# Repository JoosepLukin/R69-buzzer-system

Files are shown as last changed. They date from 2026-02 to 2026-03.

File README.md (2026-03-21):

# R69 Buzzer System

A wireless buzzer/alert system built on three custom PCBs communicating via ESP-NOW, RS-485, and 433 MHz RF. The system is designed for event/competition use where remote flash+buzzer units (Vilkur) are triggered from a central control panel (KontrollKast) with an RF-bridge board in between.

---

## System Architecture

```
                        ┌──────────────┐
  [433 MHz Remote] ────►│   Vilkur     │──── LEDs + Buzzer
                   ──┐  │  (ESP32-C3)  │
                     │  └──────────────┘
                     │         ▲▼ ESP-NOW
                     │  ┌──────────────────────┐
                     └─►│  SaatjaVastuvõtja    │
                        │     (ESP32-C3)        │
                        │  433 MHz RX + ESP-NOW │
                        └──────────┬───────────┘
                                   │ RS-485 (Cat5 cable, 12 V + GND)
                        ┌──────────▼───────────┐
                        │    KontrollKast       │
                        │      (ESP32-S3)       │
                        │  Touchscreen + Buttons│
                        │  RS-485 + 433 MHz RX  │
                        └──────────────────────┘
```

### Communication flows

| Path | Protocol | Purpose |
|---|---|---|
| KontrollKast ↔ SaatjaVastuvõtja | RS-485 JSON (115200 baud) | Commands, status, sensor data |
| SaatjaVastuvõtja ↔ Vilkur | ESP-NOW (2.4 GHz) | Blink commands, pings, status |
| 433 MHz Remote → Vilkur | ASK/OOK PT2262/EV1527 | Direct trigger (fallback) |
| 433 MHz Remote → SaatjaVastuvõtja | ASK/OOK PT2262/EV1527 | Relay to KontrollKast |
| 433 MHz Remote → KontrollKast | ASK/OOK PT2262/EV1527 | Pairing only |

---

## PCB Overview

### PCB 1 — Vilkur (`Vilkur/`)
The flash/buzzer unit. Runs on a 3S Li-ion battery pack with BMS and USB-C charging. Drives two LED groups and a piezo buzzer via N-channel MOSFETs. Listens for both ESP-NOW commands and 433 MHz RF signals (433 MHz acts as a fallback: it is automatically disabled when ESP-NOW messages are active and re-enabled after 1 minute of silence).

- **MCU**: ESP32-C3 Supermini
- **Power**: 3S 18650 Li-ion → BMS → 12 V boost → 3.3 V buck
- **Outputs**: LED group 1, LED group 2, piezo buzzer (all MOSFET low-side)
- **Inputs**: 433 MHz RXB6, rotary channel switch, pairing button, external trigger, battery ADC

### PCB 2 — KontrollKast (`KontrollKast/`)
The control centre. Powered from 12 V mains/PSU. Features a 320×480 touchscreen for configuration and status, three illuminated push-buttons for manual triggering, a 433 MHz receiver for pairing remotes, and an RS-485 link to SaatjaVastuvõtja.

- **MCU**: ESP32-S3
- **Display**: ST7796 320×480 SPI + FT6336U capacitive touch
- **Outputs**: 3× button backlight LEDs (MOSFET low-side, 12 V)
- **Inputs**: 3× push-buttons, 433 MHz RXB6 (pairing only)
- **Comms**: RS-485 (SN65HVD72) to SaatjaVastuvõtja

### PCB 3 — SaatjaVastuvõtja (`SaatjaVastuvõtja/`)
The RF bridge. Powered over Cat5 from KontrollKast (12 V). Receives 433 MHz signals and ESP-NOW messages, relaying everything to KontrollKast over RS-485. Sends ESP-NOW commands to Vilkur units based on instructions from KontrollKast.

- **MCU**: ESP32-C3 Supermini
- **Inputs**: 433 MHz RXB6, ESP-NOW from Vilkur
- **Comms**: RS-485 (SN65HVD72) to KontrollKast, ESP-NOW to Vilkur

---

## RS-485 JSON Protocol

All frames are UTF-8 text terminated with `\n`. Baud rate: **115200, 8N1**.

### SaatjaVastuvõtja → KontrollKast

```json
{"type":"433rx","code":12345678,"bits":24}
{"type":"espnow_rx","mac":"AA:BB:CC:DD:EE:FF","cmd":"blink","battery":3.72}
{"type":"ping_reply","mac":"AA:BB:CC:DD:EE:FF","battery":3.72}
{"type":"espnow_ack","mac":"AA:BB:CC:DD:EE:FF","success":true}
```

### KontrollKast → SaatjaVastuvõtja

```json
{"type":"cmd","mac":"AA:BB:CC:DD:EE:FF","action":"blink","duration":5000,"buzzer":true}
{"type":"cmd","mac":"broadcast","action":"stop"}
{"type":"cmd","mac":"AA:BB:CC:DD:EE:FF","action":"disable_433"}
{"type":"ping","mac":"AA:BB:CC:DD:EE:FF"}
{"type":"ping","mac":"broadcast"}
{"type":"pair_enable"}
```

---

## ESP-NOW Message Structure

```cpp
// Shared between Vilkur and SaatjaVastuvõtja
struct EspNowMsg {
    uint8_t  cmd;       // see CMD_* constants below
    uint16_t duration;  // blink duration ms
    bool     buzzer;    // enable buzzer during blink
    float    battery;   // Vilkur battery voltage (V), sent in pong
};

// cmd values
#define CMD_BLINK       0x01
#define CMD_STOP        0x02
#define CMD_DISABLE_433 0x03
#define CMD_PING        0x04
#define CMD_PONG        0x05
```

---

## Directory Structure

```
R69-buzzer-system/
├── README.md                        ← this file
├── Vilkur/
│   ├── README.md                    ← Vilkur detailed docs
│   └── Vilkur_Test/
│       └── Vilkur_Test.ino          ← Arduino test sketch (ESP32-C3)
├── KontrollKast/
│   ├── README.md                    ← KontrollKast detailed docs
│   └── KontrollKast_Test/
│       └── KontrollKast_Test.ino    ← Arduino test sketch (ESP32-S3)
├── SaatjaVastuvõtja/
│   ├── README.md                    ← SaatjaVastuvõtja detailed docs
│   └── SaatjaVastuvõtja_Test/
│       └── SaatjaVastuvõtja_Test.ino ← Arduino test sketch (ESP32-C3)
├── Altium/                          ← PCB design files (Altium Designer)
│   ├── Buzzer/                      ← Vilkur PCB
│   ├── KontrollKast/                ← KontrollKast PCB
│   └── VastuvotjaMoodul/            ← SaatjaVastuvõtja PCB
└── ESP-NOW Mõõtmised/               ← Range/latency measurement data & visualiser
```

---

## Required Arduino Libraries

| Library | Board | Install via |
|---|---|---|
| `esp_now.h` + `WiFi.h` | All | Built-in (ESP32 Arduino core) |
| RCSwitch | Vilkur, KontrollKast, SaatjaVastuvõtja | Arduino Library Manager |
| TFT_eSPI | KontrollKast | Arduino Library Manager |
| ArduinoJson (v6) | KontrollKast, SaatjaVastuvõtja | Arduino Library Manager |

### Arduino Board Packages
- **ESP32-C3 Supermini**: `esp32` by Espressif, board `ESP32C3 Dev Module`
- **ESP32-S3**: `esp32` by Espressif, board `ESP32S3 Dev Module`

### TFT_eSPI Configuration (KontrollKast)
Edit `libraries/TFT_eSPI/User_Setup.h`:
```cpp
#define ST7796_DRIVER
#define TFT_WIDTH  320
#define TFT_HEIGHT 480
#define TFT_CS    15
#define TFT_DC    17
#define TFT_RST   16
#define TFT_MOSI  18
#define TFT_SCLK   8
#define TFT_MISO   9
#define TFT_BL     3
#define SPI_FREQUENCY  27000000
```

---

## License

Apache License 2.0 — see [LICENSE](LICENSE).

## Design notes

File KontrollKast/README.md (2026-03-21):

# KontrollKast — Control Centre

PCB 2 of the R69 Buzzer System. The central control unit. Powered from a 12 V supply, it provides a touchscreen UI for configuration and status, three illuminated push-buttons for direct triggering, and communicates with Vilkur units indirectly through SaatjaVastuvõtja over RS-485. All ESP-NOW traffic passes through SaatjaVastuvõtja — KontrollKast itself has no wireless radio beyond the local 433 MHz receiver used only for pairing.

---

## Hardware Summary

| Component | Details |
|---|---|
| MCU | ESP32-S3 |
| Power input | Barrel jack 12 V |
| Buck converter | 12 V → 3.3 V (ESP32 + logic) |
| Display | ST7796 320×480 SPI LCD |
| Touch | FT6336U capacitive touch (I2C, addr 0x38) |
| 433 MHz RX | RXB6 module (pairing only) |
| RS-485 transceiver | SN65HVD72DGKR (half-duplex) |
| RS-485 connector | Cat5 (also carries 12 V + GND to SaatjaVastuvõtja) |
| Buttons | 3× illuminated 12 V push-buttons |
| Button connectors | NS25 W4P: 12 V, GND, backlight MOSFET, button input GPIO |

---

## GPIO Pinout (ESP32-S3)

| GPIO | Direction | Function | Notes |
|---|---|---|---|
| 1 | Input | RXB6 433 MHz data | Pairing use only |
| 3 | Output | LCD backlight PWM | `ledcWrite` for brightness control |
| 4 | Output | RS-485 DE/RE (mode) | HIGH = transmit, LOW = receive |
| 5 | Output | RS-485 TX | Serial1 TX |
| 6 | Input | RS-485 RX | Serial1 RX |
| 8 | Output | LCD SCK (SPI) | Shared SPI bus |
| 9 | Input | LCD MISO (SPI) | Shared SPI bus |
| 10 | I/O | Touch CTP_SCL (I2C) | Wire SCL |
| 11 | Output | Touch CTP_RST | Active LOW reset |
| 12 | I/O | Touch CTP_SDA (I2C) | Wire SDA |
| 13 | Input | Touch CTP_INT | LOW when touch event pending |
| 14 | Output | SD card CS | SPI chip select |
| 15 | Output | LCD CS | SPI chip select |
| 16 | Output | LCD RST | Active LOW reset |
| 17 | Output | LCD DC (RS) | HIGH = data, LOW = command |
| 18 | Output | LCD MOSI (SPI) | Shared SPI bus |
| 21 | Output | Button 1 backlight MOSFET | Active HIGH |
| 35 | Output | Button 2 backlight MOSFET | Active HIGH |
| 36 | Input | Button 2 input | Active LOW (see W4P connector) |
| 39 | Output | Button 3 backlight MOSFET | Active HIGH |
| 40 | Input | Button 3 input | Active LOW |
| 48 | Input | Button 1 input | Active LOW |

---

## Button Connector (NS25 W4P)

Each button connector carries four signals:

| Pin | Signal |
|-----|---|
| 1 | 12 V (backlight LED +) |
| 2 | GND (switch common) |
| 3 | Backlight MOSFET drain → LED – |
| 4 | Button switch output → GPIO input |

The button switch is wired between pin 4 and GND (pin 2). The GPIO uses `INPUT_PULLUP`; pressing the button pulls it LOW.

---

## Display — ST7796 + FT6336U

### SPI LCD (ST7796, 320×480)
```
ESP32-S3 GPIO  │ Ribbon pin │ Function
───────────────┼────────────┼──────────────────
GPIO 15        │ LCD_CS     │ Chip select (active LOW)
GPIO 16        │ LCD_RST    │ Reset (active LOW)
GPIO 17        │ LCD_RS/DC  │ Command=LOW / Data=HIGH
GPIO 18        │ SDI/MOSI   │ SPI data in
GPIO  8        │ SCK        │ SPI clock
GPIO  9        │ SDO/MISO   │ SPI data out
GPIO  3        │ LED        │ Backlight (PWM)
3.3 V          │ VCC        │ Logic power (backlight dim at 3.3 V)
```

> **Note**: The module datasheet recommends 5 V for full backlight brightness. At 3.3 V the backlight will be slightly dimmer but fully functional.

### Capacitive Touch (FT6336U, I2C address 0x38)
```
ESP32-S3 GPIO  │ Ribbon pin │ Function
───────────────┼────────────┼──────────────────
GPIO 10        │ CTP_SCL    │ I2C clock
GPIO 12        │ CTP_SDA    │ I2C data
GPIO 11        │ CTP_RST    │ Controller reset (active LOW)
GPIO 13        │ CTP_INT    │ Touch interrupt (active LOW)
```

Key FT6336U registers (read via Wire at address 0x38):

| Register | Name | Description |
|---|---|---|
| 0x02 | TD_STATUS | Number of touch points (0 or 1) |
| 0x03 | P1_XH | Touch 1 X high byte (bits [3:0]) + event flag |
| 0x04 | P1_XL | Touch 1 X low byte |
| 0x05 | P1_YH | Touch 1 Y high byte (bits [3:0]) |
| 0x06 | P1_YL | Touch 1 Y low byte |

### TFT_eSPI Configuration

Add to `libraries/TFT_eSPI/User_Setup.h`:
```cpp
#define ST7796_DRIVER
#define TFT_WIDTH  320
#define TFT_HEIGHT 480
#define TFT_CS    15
#define TFT_DC    17
#define TFT_RST   16
#define TFT_MOSI  18
#define TFT_SCLK   8
#define TFT_MISO   9
#define TFT_BL     3
#define SPI_FREQUENCY     27000000
#define SPI_READ_FREQUENCY 20000000
```

---

## RS-485 Interface

- **Transceiver**: SN65HVD72DGKR (3.3 V, half-duplex)
- **Mode pin** (GPIO 4): HIGH = transmit (DE+RE asserted), LOW = receive
- **Baud rate**: 115200, 8N1
- **Physical**: Differential pair over Cat5 cable; same cable carries 12 V and GND to power SaatjaVastuvõtja

```cpp
Serial1.begin(115200, SERIAL_8N1, /*RX=*/6, /*TX=*/5);
```

Transmit procedure:
1. `digitalWrite(RS485_MODE, HIGH);`
2. `Serial1.println(jsonString);`
3. `Serial1.flush();`
4. `digitalWrite(RS485_MODE, LOW);`

---

## Behaviour Logic

### Startup
1. Initialize display → splash screen.
2. Initialize touch controller.
3. Initialize RS-485 and send a broadcast ping to discover connected Vilkur units.
4. Show main UI.

### Main UI (touchscreen)
- **Status panel**: Connected Vilkur list (MAC, battery voltage, last-seen).
- **Manual trigger buttons** (on screen and physical buttons):
  - Blink All — broadcast `CMD_BLINK` to all Vilkurs via RS-485 → SaatjaVastuvõtja
  - Stop All — broadcast `CMD_STOP`
  - Ping All — send ping broadcast; update status panel on reply
- **Settings page** (touch navigation):
  - Blink duration (ms)
  - Buzzer on/off during blink
  - ESP-NOW channel selection (must match rotary switch on Vilkur)
  - 433 MHz pairing mode

### Physical buttons
Each physical button (1, 2, 3) can be assigned to a specific Vilkur or broadcast group. Pressing a button sends `CMD_BLINK` to its assigned target. The corresponding backlight LED lights up while the Vilkur is blinking.

### 433 MHz pairing mode
Activated from the settings page or by a long-press on button 1. The on-board RXB6 receiver listens for the next PT2262/EV1527 code and stores it as an authorised trigger code. This code is then relayed to SaatjaVastuvõtja (and onward to Vilkurs) so that the remote directly triggers blinking.

### Vilkur monitoring (ping)
Every 5 seconds KontrollKast sends `{"type":"ping","mac":"broadcast"}` over RS-485. SaatjaVastuvõtja forwards this as ESP-NOW `CMD_PING`. Vilkur replies with `CMD_PONG` (including battery voltage). SaatjaVastuvõtja relays the reply back over RS-485 as `{"type":"ping_reply",...}`. KontrollKast marks the Vilkur as connected and updates its voltage on screen.

---

## Required Libraries

| Library | Source |
|---|---|
| TFT_eSPI | Arduino Library Manager |
| ArduinoJson (v6) | Arduino Library Manager |
| RCSwitch (by sui77) | Arduino Library Manager |
| `Wire.h` | Built-in (ESP32 Arduino core) |
| `HardwareSerial` | Built-in (ESP32 Arduino core) |

---

## Test Sketch

See [`KontrollKast_Test/KontrollKast_Test.ino`](KontrollKast_Test/KontrollKast_Test.ino).

The test sketch exercises:
- ST7796 display (colour fill, text rendering)
- FT6336U touch (live X/Y display)
- Three physical buttons + backlight LEDs
- 433 MHz reception (code displayed on screen + Serial)
- RS-485 TX/RX (periodic ping to SaatjaVastuvõtja, display replies)
- On-screen touch buttons: Blink All, Stop All, Ping All, 433 Pair

Open Serial monitor at **115200 baud** for debug output.

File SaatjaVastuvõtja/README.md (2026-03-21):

# SaatjaVastuvõtja — RF Bridge

PCB 3 of the R69 Buzzer System. A small bridge board that sits physically close to the event area and connects KontrollKast (wired, over Cat5 RS-485) to Vilkur units (wireless, ESP-NOW). It also forwards 433 MHz RF signals received from remotes to KontrollKast over RS-485.

The name combines the Estonian words *saatja* (sender) and *vastuvõtja* (receiver), reflecting its dual transmit/receive role.

---

## Hardware Summary

| Component | Details |
|---|---|
| MCU | ESP32-C3 Supermini |
| Power input | Cat5 connector — 12 V from KontrollKast |
| Buck converter | 12 V → 3.3 V (ESP32 + logic) |
| 433 MHz RX | RXB6 module |
| RS-485 transceiver | SN65HVD72DGKR (half-duplex, same chip as KontrollKast) |
| RS-485 connector | Cat5 (12 V, GND, RS-485 A/B from KontrollKast) |

---

## GPIO Pinout (ESP32-C3 Supermini)

| GPIO | Direction | Function | Notes |
|---|---|---|---|
| 1 | Output | RS-485 DE/RE (mode) | HIGH = transmit, LOW = receive |
| 2 | Output | RS-485 TX | Serial1 TX |
| 3 | Input | RS-485 RX | Serial1 RX |
| 4 | Input | RXB6 433 MHz data | Interrupt-driven |

---

## RS-485 Interface

- **Transceiver**: SN65HVD72DGKR, same as KontrollKast
- **Mode pin** (GPIO 1): HIGH = transmit, LOW = receive
- **Baud rate**: 115200, 8N1
- **Physical**: Differential pair over Cat5 cable to KontrollKast

```cpp
Serial1.begin(115200, SERIAL_8N1, /*RX=*/3, /*TX=*/2);
```

Transmit procedure:
1. `digitalWrite(RS485_MODE, HIGH);`
2. `Serial1.println(jsonString);`
3. `Serial1.flush();`
4. `digitalWrite(RS485_MODE, LOW);`

---

## Behaviour Logic

### 433 MHz reception
1. RCSwitch library decodes PT2262/EV1527 codes on GPIO 4.
2. On valid code reception → relay immediately over RS-485 to KontrollKast:
   ```json
   {"type":"433rx","code":12345678,"bits":24}
   ```

### RS-485 reception (commands from KontrollKast)
All incoming JSON frames are parsed with ArduinoJson. Supported commands:

| `type` field | `action` / behaviour | ESP-NOW sent |
|---|---|---|
| `cmd` + `action:"blink"` | Forward blink command to target MAC (or broadcast) | `CMD_BLINK` with `duration`, `buzzer` |
| `cmd` + `action:"stop"` | Stop blinking | `CMD_STOP` |
| `cmd` + `action:"disable_433"` | Disable 433 MHz fallback on Vilkur | `CMD_DISABLE_433` |
| `ping` | Send ESP-NOW ping, await pong, relay reply | `CMD_PING` |
| `pair_enable` | Enter 433 MHz pairing mode: next received code sent back over RS-485 | — |

### ESP-NOW reception (from Vilkur)
Any incoming ESP-NOW frame is immediately relayed over RS-485 to KontrollKast:

```json
{"type":"espnow_rx","mac":"AA:BB:CC:DD:EE:FF","cmd":"pong","battery":11.82}
```

For ping replies specifically:
```json
{"type":"ping_reply","mac":"AA:BB:CC:DD:EE:FF","battery":11.82}
```

### ESP-NOW channel
Must match the rotary switch setting on the target Vilkur units (channel 1, 6, or 11). During testing, channel 1 is the default.

---

## ESP-NOW Message Structure

```cpp
struct EspNowMsg {
    uint8_t  cmd;       // CMD_BLINK / CMD_STOP / CMD_DISABLE_433 / CMD_PING / CMD_PONG
    uint16_t duration;  // blink duration ms (CMD_BLINK only)
    bool     buzzer;    // enable buzzer (CMD_BLINK only)
    float    battery;   // Vilkur battery V (CMD_PONG only)
};

#define CMD_BLINK       0x01
#define CMD_STOP        0x02
#define CMD_DISABLE_433 0x03
#define CMD_PING        0x04
#define CMD_PONG        0x05
```

ESP-NOW broadcast address `FF:FF:FF:FF:FF:FF` is used to reach all Vilkur units simultaneously when `mac:"broadcast"` is received from KontrollKast.

---

## Required Libraries

| Library | Source |
|---|---|
| `esp_now.h` | Built-in (ESP32 Arduino core) |
| `WiFi.h` | Built-in (ESP32 Arduino core) |
| RCSwitch (by sui77) | Arduino Library Manager |
| ArduinoJson (v6) | Arduino Library Manager |

---

## Test Sketch

See [`SaatjaVastuvõtja_Test/SaatjaVastuvõtja_Test.ino`](SaatjaVastuvõtja_Test/SaatjaVastuvõtja_Test.ino).

The test sketch exercises:
- 433 MHz reception (prints decoded codes to Serial + relays to KontrollKast over RS-485)
- RS-485 RX: parses JSON commands from KontrollKast, executes ESP-NOW sends
- ESP-NOW RX: relays Vilkur messages to KontrollKast over RS-485
- Serial mirror of all RS-485 traffic at 115200 baud for debug

### Test sequence (with all three boards connected)
1. Open Serial monitors on all three boards.
2. Trigger 433 MHz remote → code appears on KontrollKast Serial/screen and here.
3. From KontrollKast (touch "Ping All") → JSON frame visible on this board's Serial → ESP-NOW ping sent → Vilkur pong received → relay to KontrollKast.
4. From KontrollKast (touch "Blink All") → CMD_BLINK sent via ESP-NOW → Vilkur LEDs blink.

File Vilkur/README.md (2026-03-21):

# Vilkur — Flash & Buzzer Unit

PCB 1 of the R69 Buzzer System. A battery-powered wireless flash/buzzer node that responds to both ESP-NOW commands (primary) and 433 MHz RF signals (fallback). Multiple Vilkur units can operate simultaneously on the same ESP-NOW channel.

---

## Hardware Summary

| Component | Details |
|---|---|
| MCU | ESP32-C3 Supermini |
| Battery | 3S Li-ion (three 18650 cells in holders) |
| BMS | Soldered directly to PCB |
| Charging | USB-C connector → boost charger module (5 V in, ~12.6 V out); charge indicator LED on underside (ON while charging) |
| On/Off switch | Connects battery pack to BMS + rest of circuit |
| Buck converter | 12 V → 3.3 V (powers ESP32 and logic) |
| Battery indicator | Push-to-read voltage display connected directly to battery |
| 433 MHz RX | RXB6 module |
| Outputs | LED group 1, LED group 2, piezo buzzer — all N-MOSFET low-side switched |
| Connectors | NS25 W2P for each MOSFET output; NS25 W2P for external signal |

---

## GPIO Pinout (ESP32-C3 Supermini)

| GPIO | Direction | Function | Notes |
|---|---|---|---|
| 0 | Input | RXB6 433 MHz data | Strapping pin — idle HIGH; avoid pulling LOW at boot |
| 1 | Output | Pairing feedback LED | Active HIGH |
| 2 | Output | Piezo buzzer (MOSFET gate) | 100 Ω series to gate; 10 kΩ pull-down |
| 3 | Output | LED group 2 (MOSFET gate) | 100 Ω series to gate; 10 kΩ pull-down |
| 4 | Output | LED group 1 (MOSFET gate) | 100 Ω series to gate; 10 kΩ pull-down |
| 5 | Input (ADC) | Battery voltage divider | Reads ¼ of battery voltage; multiply by 4 to get real V |
| 8 | Input | External signal | Pulled HIGH externally when connector is bridged |
| 9 | Input | Pairing tactile button | Active LOW (to GND); use INPUT_PULLUP |
| 10 | Input | Rotary switch position 1 | LOW = channel 1 selected; use INPUT_PULLUP |
| 20 | Input | Rotary switch position 2 | LOW = channel 6 selected; use INPUT_PULLUP |
| 21 | Input | Rotary switch position 3 | LOW = channel 11 selected; use INPUT_PULLUP |

### USB Data Pass-through
The USB-C data pins are routed via NS25 W2P connector to the ESP32-C3 Supermini's USB data pads, allowing firmware flashing without removing the module.

---

## Power Path

```
18650 × 3 (3S)
    │
    ├──► Battery voltage indicator (direct, push-to-read)
    │
    ▼
   BMS
    │
On/Off switch
    │
    ├──► USB boost charger module (USB-C in)
    │         └── Charge LED (bottom of PCB, ON while charging)
    │
    └──► 12 V rail
              │
              ├──► Buck converter → 3.3 V → ESP32-C3 + logic
              ├──► LED group 1 (via MOSFET)
              ├──► LED group 2 (via MOSFET)
              └──► Piezo buzzer (via MOSFET)
```

### Battery Voltage ADC
```
Battery (+) ──[R1]──┬──[R2]── GND
                    │
                  GPIO 5 (ADC)

Ratio: 1/4  →  GPIO5 reads ¼ of battery voltage
Real voltage = ADC_raw × (3.3 / 4095) × 4
Healthy 3S range: ~9.0 V (empty) – 12.6 V (full)
```

---

## MOSFET Output Circuit

Each of the three outputs (LED group 1, LED group 2, buzzer) uses the same circuit:

```
GPIO_x ──[100 Ω]── GATE
                     │
                   N-FET
                     │
                  DRAIN ── Load (–)   Load (+) ── 12 V (via NS25 connector)
                     │
                  SOURCE ── GND
                     │
                  [10 kΩ pull-down to GND]
```

---

## Rotary Switch — ESP-NOW Channel Selection

The 3-position rotary switch selects the Wi-Fi channel used by ESP-NOW. SaatjaVastuvõtja must be configured to the same channel.

| GPIO 10 | GPIO 20 | GPIO 21 | Channel |
|---|---|---|---|
| LOW | HIGH | HIGH | 1 (default) |
| HIGH | LOW | HIGH | 6 |
| HIGH | HIGH | LOW | 11 |
| HIGH | HIGH | HIGH | 1 (fallback) |

---

## Behaviour Logic

### Normal operation
1. On power-up: short self-test (blink + buzz).
2. Listen for ESP-NOW messages on the selected channel.
3. Listen for 433 MHz PT2262/EV1527 codes (fallback, always active unless disabled).

### ESP-NOW commands received
| Command | Action |
|---|---|
| `CMD_BLINK` | Blink LED groups in pattern, optionally enable buzzer, for `duration` ms |
| `CMD_STOP` | Immediately stop blinking/buzzing |
| `CMD_DISABLE_433` | Stop listening to 433 MHz receiver |
| `CMD_PING` | Reply with `CMD_PONG` including current battery voltage |

### 433 MHz fallback
- **Active by default**.
- Disabled when `CMD_DISABLE_433` is received via ESP-NOW.
- **Auto re-enabled** after **60 seconds** of no ESP-NOW messages (watchdog timer).
- Rationale: if the ESP-NOW link is lost the Vilkur remains controllable by 433 MHz remote.

### Pairing mode (button GPIO 9, hold 3 s)
1. Feedback LED (GPIO 1) blinks rapidly.
2. First 433 MHz code received is stored in NVM as the "paired code".
3. LED stops blinking; pairing complete.
4. Only the paired code triggers the unit in 433 MHz mode.

### External signal (GPIO 8)
When the NS25 connector is externally bridged to 3.3 V the pin reads HIGH. Can be used to trigger the unit from a wired signal.

---

## Required Libraries

| Library | Source |
|---|---|
| `esp_now.h` | Built-in (ESP32 Arduino core) |
| `WiFi.h` | Built-in (ESP32 Arduino core) |
| RCSwitch (by sui77) | Arduino Library Manager |

---

## Test Sketch

See [`Vilkur_Test/Vilkur_Test.ino`](Vilkur_Test/Vilkur_Test.ino).

The test sketch exercises:
- LED group 1 & 2 blink patterns
- Piezo buzzer
- Battery voltage ADC reading
- Rotary switch position detection
- External signal pin reading
- 433 MHz reception (prints received codes to Serial)
- ESP-NOW broadcast receive/transmit
- Pairing button (hold 3 s)

Open Serial monitor at **115200 baud** and follow the menu.

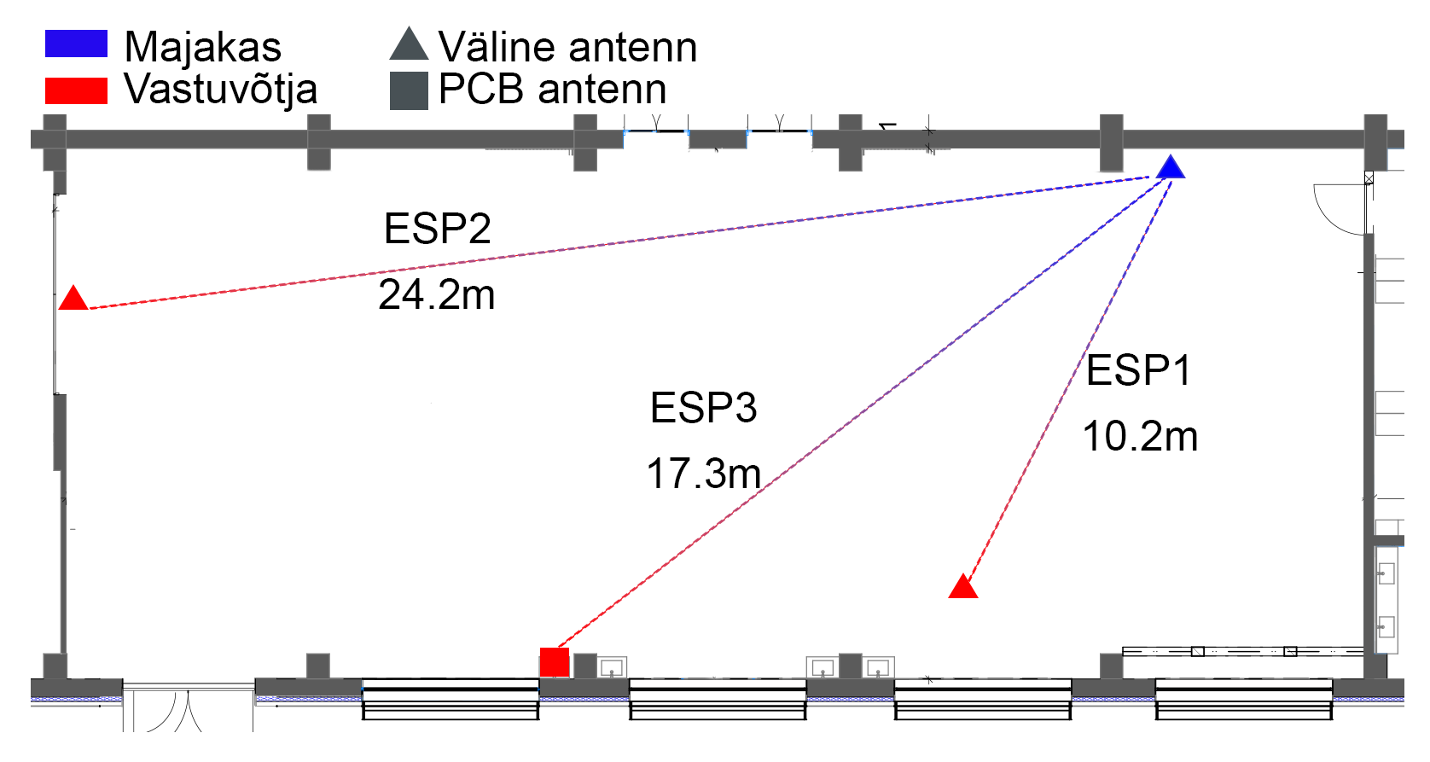
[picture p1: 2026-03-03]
ESP-NOW Mõõtmised/Põrandaplaan.png

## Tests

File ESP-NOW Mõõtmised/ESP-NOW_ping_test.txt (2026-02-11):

--- Session start 2026-01-07T14:25:49 ---
{"t_ms":601352,"seq":1199,"slave_index":1,"responder_id":null,"rtt_us":null,"status":"PING_FAILED"}
{"t_ms":601352,"seq":1200,"slave_index":2,"status":"PING_SENT"}
{"t_ms":601364,"seq":1200,"slave_index":2,"responder_id":3,"rtt_us":11693,"status":"OK"}
{"t_ms":601857,"seq":1201,"slave_index":0,"status":"PING_SENT"}
{"t_ms":601859,"seq":1201,"slave_index":0,"responder_id":1,"rtt_us":1963,"status":"OK"}
{"t_ms":602357,"seq":1202,"slave_index":1,"status":"PING_SENT"}
{"t_ms":602361,"seq":1202,"slave_index":1,"responder_id":2,"rtt_us":4263,"status":"OK"}
{"t_ms":602857,"seq":1203,"slave_index":2,"status":"PING_SENT"}
{"t_ms":602859,"seq":1203,"slave_index":2,"responder_id":3,"rtt_us":2264,"status":"OK"}
{"t_ms":603357,"seq":1204,"slave_index":0,"status":"PING_SENT"}
{"t_ms":603364,"seq":1204,"slave_index":0,"responder_id":1,"rtt_us":7144,"status":"OK"}
{"t_ms":603862,"seq":1205,"slave_index":1,"status":"PING_SENT"}
{"t_ms":603866,"seq":1205,"slave_index":1,"responder_id":2,"rtt_us":3723,"status":"OK"}
{"t_ms":604362,"seq":1206,"slave_index":2,"status":"PING_SENT"}
{"t_ms":604367,"seq":1206,"slave_index":2,"responder_id":3,"rtt_us":4750,"status":"OK"}
{"t_ms":604862,"seq":1207,"slave_index":0,"status":"PING_SENT"}
{"t_ms":604868,"seq":1207,"slave_index":0,"responder_id":1,"rtt_us":6084,"status":"OK"}
{"t_ms":605362,"seq":1208,"slave_index":1,"status":"PING_SENT"}
{"t_ms":605867,"seq":1208,"slave_index":1,"responder_id":null,"rtt_us":null,"status":"PING_FAILED"}
{"t_ms":605867,"seq":1209,"slave_index":2,"status":"PING_SENT"}
{"t_ms":605871,"seq":1209,"slave_index":2,"responder_id":3,"rtt_us":3390,"status":"OK"}
{"t_ms":606367,"seq":1210,"slave_index":0,"status":"PING_SENT"}
{"t_ms":606379,"seq":1210,"slave_index":0,"responder_id":1,"rtt_us":11726,"status":"OK"}
{"t_ms":606867,"seq":1211,"slave_index":1,"status":"PING_SENT"}
{"t_ms":606874,"seq":1211,"slave_index":1,"responder_id":2,"rtt_us":7263,"status":"OK"}
{"t_ms":607367,"seq":1212,"slave_index":2,"status":"PING_SENT"}
{"t_ms":607372,"seq":1212,"slave_index":2,"responder_id":3,"rtt_us":4750,"status":"OK"}
{"t_ms":607872,"seq":1213,"slave_index":0,"status":"PING_SENT"}
{"t_ms":607878,"seq":1213,"slave_index":0,"responder_id":1,"rtt_us":6415,"status":"OK"}
{"t_ms":608372,"seq":1214,"slave_index":1,"status":"PING_SENT"}
{"t_ms":608377,"seq":1214,"slave_index":1,"responder_id":2,"rtt_us":4947,"status":"OK"}
{"t_ms":608872,"seq":1215,"slave_index":2,"status":"PING_SENT"}
{"t_ms":608874,"seq":1215,"slave_index":2,"responder_id":3,"rtt_us":1794,"status":"OK"}
{"t_ms":609372,"seq":1216,"slave_index":0,"status":"PING_SENT"}
{"t_ms":609877,"seq":1216,"slave_index":0,"responder_id":null,"rtt_us":null,"status":"PING_FAILED"}
{"t_ms":609877,"seq":1217,"slave_index":1,"status":"PING_SENT"}
{"t_ms":609880,"seq":1217,"slave_index":1,"responder_id":2,"rtt_us":3248,"status":"OK"}
{"t_ms":610377,"seq":1218,"slave_index":2,"status":"PING_SENT"}
{"t_ms":610379,"seq":1218,"slave_index":2,"responder_id":3,"rtt_us":1785,"status":"OK"}
{"t_ms":610877,"seq":1219,"slave_index":0,"status":"PING_SENT"}
{"t_ms":610903,"seq":1219,"slave_index":0,"responder_id":1,"rtt_us":26063,"status":"OK"}
{"t_ms":611377,"seq":1220,"slave_index":1,"status":"PING_SENT"}
{"t_ms":611383,"seq":1220,"slave_index":1,"responder_id":2,"rtt_us":6356,"status":"OK"}
{"t_ms":611882,"seq":1221,"slave_index":2,"status":"PING_SENT"}
{"t_ms":611884,"seq":1221,"slave_index":2,"responder_id":3,"rtt_us":1938,"status":"OK"}
{"t_ms":612382,"seq":1222,"slave_index":0,"status":"PING_SENT"}
{"t_ms":612384,"seq":1222,"slave_index":0,"responder_id":1,"rtt_us":2088,"status":"OK"}
{"t_ms":612882,"seq":1223,"slave_index":1,"status":"PING_SENT"}
{"t_ms":612884,"seq":1223,"slave_index":1,"responder_id":2,"rtt_us":1987,"status":"OK"}
{"t_ms":613382,"seq":1224,"slave_index":2,"status":"PING_SENT"}
{"t_ms":613384,"seq":1224,"slave_index":2,"responder_id":3,"rtt_us":1783,"status":"OK"}
{"t_ms":613887,"seq":1225,"slave_index":0,"status":"PING_SENT"}
{"t_ms":613889,"seq":1225,"slave_index":0,"responder_id":1,"rtt_us":1955,"status":"OK"}
{"t_ms":614387,"seq":1226,"slave_index":1,"status":"PING_SENT"}
{"t_ms":614390,"seq":1226,"slave_index":1,"responder_id":2,"rtt_us":3425,"status":"OK"}
{"t_ms":614887,"seq":1227,"slave_index":2,"status":"PING_SENT"}
{"t_ms":614894,"seq":1227,"slave_index":2,"responder_id":3,"rtt_us":7356,"status":"OK"}
{"t_ms":615387,"seq":1228,"slave_index":0,"status":"PING_SENT"}
{"t_ms":615393,"seq":1228,"slave_index":0,"responder_id":1,"rtt_us":5718,"status":"OK"}
{"t_ms":615892,"seq":1229,"slave_index":1,"status":"PING_SENT"}
{"t_ms":615896,"seq":1229,"slave_index":1,"responder_id":2,"rtt_us":3679,"status":"OK"}
{"t_ms":616392,"seq":1230,"slave_index":2,"status":"PING_SENT"}
{"t_ms":616396,"seq":1230,"slave_index":2,"responder_id":3,"rtt_us":3481,"status":"OK"}
{"t_ms":616892,"seq":1231,"slave_index":0,"status":"PING_SENT"}
{"t_ms":616896,"seq":1231,"slave_index":0,"responder_id":1,"rtt_us":3808,"status":"OK"}
{"t_ms":617392,"seq":1232,"slave_index":1,"status":"PING_SENT"}
{"t_ms":617897,"seq":1232,"slave_index":1,"responder_id":null,"rtt_us":null,"status":"PING_FAILED"}
{"t_ms":617897,"seq":1233,"slave_index":2,"status":"PING_SENT"}
{"t_ms":617902,"seq":1233,"slave_index":2,"responder_id":3,"rtt_us":4386,"status":"OK"}
{"t_ms":618397,"seq":1234,"slave_index":0,"status":"PING_SENT"}
{"t_ms":618400,"seq":1234,"slave_index":0,"responder_id":1,"rtt_us":3456,"status":"OK"}
{"t_ms":618897,"seq":1235,"slave_index":1,"status":"PING_SENT"}
{"t_ms":618899,"seq":1235,"slave_index":1,"responder_id":2,"rtt_us":1958,"status":"OK"}
{"t_ms":619397,"seq":1236,"slave_index":2,"status":"PING_SENT"}
{"t_ms":619429,"seq":1236,"slave_index":2,"responder_id":3,"rtt_us":32180,"status":"OK"}
{"t_ms":619902,"seq":1237,"slave_index":0,"status":"PING_SENT"}
{"t_ms":619906,"seq":1237,"slave_index":0,"responder_id":1,"rtt_us":3575,"status":"OK"}
{"t_ms":620402,"seq":1238,"slave_index":1,"status":"PING_SENT"}
{"t_ms":620412,"seq":1238,"slave_index":1,"responder_id":2,"rtt_us":9685,"status":"OK"}
{"t_ms":620902,"seq":1239,"slave_index":2,"status":"PING_SENT"}
{"t_ms":620906,"seq":1239,"slave_index":2,"responder_id":3,"rtt_us":3861,"status":"OK"}
{"t_ms":621402,"seq":1240,"slave_index":0,"status":"PING_SENT"}
{"t_ms":621405,"seq":1240,"slave_index":0,"responder_id":1,"rtt_us":2744,"status":"OK"}
{"t_ms":621907,"seq":1241,"slave_index":1,"status":"PING_SENT"}
{"t_ms":621914,"seq":1241,"slave_index":1,"responder_id":2,"rtt_us":7174,"status":"OK"}
{"t_ms":622407,"seq":1242,"slave_index":2,"status":"PING_SENT"}
{"t_ms":622413,"seq":1242,"slave_index":2,"responder_id":3,"rtt_us":5626,"status":"OK"}
{"t_ms":622907,"seq":1243,"slave_index":0,"status":"PING_SENT"}
{"t_ms":622909,"seq":1243,"slave_index":0,"responder_id":1,"rtt_us":1940,"status":"OK"}
{"t_ms":623407,"seq":1244,"slave_index":1,"status":"PING_SENT"}
{"t_ms":623411,"seq":1244,"slave_index":1,"responder_id":2,"rtt_us":3532,"status":"OK"}
{"t_ms":623912,"seq":1245,"slave_index":2,"status":"PING_SENT"}
{"t_ms":623915,"seq":1245,"slave_index":2,"responder_id":3,"rtt_us":2638,"status":"OK"}
{"t_ms":624412,"seq":1246,"slave_index":0,"status":"PING_SENT"}
{"t_ms":624416,"seq":1246,"slave_index":0,"responder_id":1,"rtt_us":4164,"status":"OK"}
{"t_ms":624912,"seq":1247,"slave_index":1,"status":"PING_SENT"}
{"t_ms":624915,"seq":1247,"slave_index":1,"responder_id":2,"rtt_us":2857,"status":"OK"}
{"t_ms":625412,"seq":1248,"slave_index":2,"status":"PING_SENT"}
{"t_ms":625414,"seq":1248,"slave_index":2,"responder_id":3,"rtt_us":1806,"status":"OK"}
{"t_ms":625917,"seq":1249,"slave_index":0,"status":"PING_SENT"}
{"t_ms":625919,"seq":1249,"slave_index":0,"responder_id":1,"rtt_us":2160,"status":"OK"}
{"t_ms":626417,"seq":1250,"slave_index":1,"status":"PING_SENT"}
{"t_ms":626419,"seq":1250,"slave_index":1,"responder_id":2,"rtt_us":1964,"status":"OK"}
{"t_ms":626917,"seq":1251,"slave_index":2,"status":"PING_SENT"}
{"t_ms":626919,"seq":1251,"slave_index":2,"responder_id":3,"rtt_us":1777,"status":"OK"}
{"t_ms":627417,"seq":1252,"slave_index":0,"status":"PING_SENT"}
{"t_ms":627419,"seq":1252,"slave_index":0,"responder_id":1,"rtt_us":1927,"status":"OK"}
{"t_ms":627922,"seq":1253,"slave_index":1,"status":"PING_SENT"}
{"t_ms":627931,"seq":1253,"slave_index":1,"responder_id":2,"rtt_us":8750,"status":"OK"}
{"t_ms":628422,"seq":1254,"slave_index":2,"status":"PING_SENT"}
{"t_ms":628428,"seq":1254,"slave_index":2,"responder_id":3,"rtt_us":6048,"status":"OK"}
{"t_ms":628922,"seq":1255,"slave_index":0,"status":"PING_SENT"}
{"t_ms":628924,"seq":1255,"slave_index":0,"responder_id":1,"rtt_us":2081,"status":"OK"}
{"t_ms":629422,"seq":1256,"slave_index":1,"status":"PING_SENT"}
{"t_ms":629442,"seq":1256,"slave_index":1,"responder_id":2,"rtt_us":20402,"status":"OK"}
{"t_ms":629927,"seq":1257,"slave_index":2,"status":"PING_SENT"}
{"t_ms":629934,"seq":1257,"slave_index":2,"responder_id":3,"rtt_us":6937,"status":"OK"}
{"t_ms":630427,"seq":1258,"slave_index":0,"status":"PING_SENT"}
{"t_ms":630429,"seq":1258,"slave_index":0,"responder_id":1,"rtt_us":2345,"status":"OK"}
{"t_ms":630927,"seq":1259,"slave_index":1,"status":"PING_SENT"}
{"t_ms":631427,"seq":1259,"slave_index":1,"responder_id":null,"rtt_us":null,"status":"PING_FAILED"}
{"t_ms":631427,"seq":1260,"slave_index":2,"status":"PING_SENT"}
{"t_ms":631429,"seq":1260,"slave_index":2,"responder_id":3,"rtt_us":1881,"status":"OK"}
{"t_ms":631932,"seq":1261,"slave_index":0,"status":"PING_SENT"}
{"t_ms":631934,"seq":1261,"slave_index":0,"responder_id":1,"rtt_us":1939,"status":"OK"}
{"t_ms":632432,"seq":1262,"slave_index":1,"status":"PING_SENT"}
{"t_ms":632434,"seq":1262,"slave_index":1,"responder_id":2,"rtt_us":2334,"status":"OK"}
{"t_ms":632932,"seq":1263,"slave_index":2,"status":"PING_SENT"}
{"t_ms":632968,"seq":1263,"slave_index":2,"responder_id":3,"rtt_us":35985,"status":"OK"}
{"t_ms":633432,"seq":1264,"slave_index":0,"status":"PING_SENT"}
{"t_ms":633434,"seq":1264,"slave_index":0,"responder_id":1,"rtt_us":1946,"status":"OK"}
{"t_ms":633937,"seq":1265,"slave_index":1,"status":"PING_SENT"}
{"t_ms":634437,"seq":1265,"slave_index":1,"responder_id":null,"rtt_us":null,"status":"PING_FAILED"}
{"t_ms":634437,"seq":1266,"slave_index":2,"status":"PING_SENT"}
{"t_ms":634444,"seq":1266,"slave_index":2,"responder_id":3,"rtt_us":6591,"status":"OK"}
{"t_ms":634937,"seq":1267,"slave_index":0,"status":"PING_SENT"}
{"t_ms":634941,"seq":1267,"slave_index":0,"responder_id":1,"rtt_us":3828,"status":"OK"}
{"t_ms":635437,"seq":1268,"slave_index":1,"status":"PING_SENT"}
{"t_ms":635942,"seq":1268,"slave_index":1,"responder_id":null,"rtt_us":null,"status":"PING_FAILED"}
{"t_ms":635942,"seq":1269,"slave_index":2,"status":"PING_SENT"}
{"t_ms":635944,"seq":1269,"slave_index":2,"responder_id":3,"rtt_us":1848,"status":"OK"}
--- Session end 2026-01-07T14:26:24 ---
--- Session start 2026-01-07T14:26:55 ---
{"t_ms":30438,"seq":61,"slave_index":0,"status":"PING_SENT"}
{"t_ms":30444,"seq":61,"slave_index":0,"responder_id":1,"rtt_us":6314,"status":"OK"}
{"t_ms":30938,"seq":62,"slave_index":1,"status":"PING_SENT"}
{"t_ms":30943,"seq":62,"slave_index":1,"responder_id":2,"rtt_us":5159,"status":"OK"}
{"t_ms":31438,"seq":63,"slave_index":2,"status":"PING_SENT"}
{"t_ms":31442,"seq":63,"slave_index":2,"responder_id":3,"rtt_us":3860,"status":"OK"}
{"t_ms":31938,"seq":64,"slave_index":0,"status":"PING_SENT"}
{"t_ms":31942,"seq":64,"slave_index":0,"responder_id":1,"rtt_us":4152,"status":"OK"}
{"t_ms":32443,"seq":65,"slave_index":1,"status":"PING_SENT"}
{"t_ms":32448,"seq":65,"slave_index":1,"responder_id":2,"rtt_us":5402,"status":"OK"}
{"t_ms":32943,"seq":66,"slave_index":2,"status":"PING_SENT"}
{"t_ms":32945,"seq":66,"slave_index":2,"responder_id":3,"rtt_us":1903,"status":"OK"}
{"t_ms":33443,"seq":67,"slave_index":0,"status":"PING_SENT"}
{"t_ms":33447,"seq":67,"slave_index":0,"responder_id":1,"rtt_us":4370,"status":"OK"}
{"t_ms":33943,"seq":68,"slave_index":1,"status":"PING_SENT"}
{"t_ms":33952,"seq":68,"slave_index":1,"responder_id":2,"rtt_us":8780,"status":"OK"}
{"t_ms":34448,"seq":69,"slave_index":2,"status":"PING_SENT"}
{"t_ms":34450,"seq":69,"slave_index":2,"responder_id":3,"rtt_us":2165,"status":"OK"}
{"t_ms":34948,"seq":70,"slave_index":0,"status":"PING_SENT"}
{"t_ms":34950,"seq":70,"slave_index":0,"responder_id":1,"rtt_us":2031,"status":"OK"}
{"t_ms":35448,"seq":71,"slave_index":1,"status":"PING_SENT"}
{"t_ms":35456,"seq":71,"slave_index":1,"responder_id":2,"rtt_us":7878,"status":"OK"}
{"t_ms":35948,"seq":72,"slave_index":2,"status":"PING_SENT"}
{"t_ms":35950,"seq":72,"slave_index":2,"responder_id":3,"rtt_us":1968,"status":"OK"}
{"t_ms":36453,"seq":73,"slave_index":0,"status":"PING_SENT"}
{"t_ms":36455,"seq":73,"slave_index":0,"responder_id":1,"rtt_us":1929,"status":"OK"}
{"t_ms":36953,"seq":74,"slave_index":1,"status":"PING_SENT"}
{"t_ms":36967,"seq":74,"slave_index":1,"responder_id":2,"rtt_us":13707,"status":"OK"}
{"t_ms":37453,"seq":75,"slave_index":2,"status":"PING_SENT"}
{"t_ms":37455,"seq":75,"slave_index":2,"responder_id":3,"rtt_us":2118,"status":"OK"}
{"t_ms":37953,"seq":76,"slave_index":0,"status":"PING_SENT"}
{"t_ms":37955,"seq":76,"slave_index":0,"responder_id":1,"rtt_us":1976,"status":"OK"}
{"t_ms":38458,"seq":77,"slave_index":1,"status":"PING_SENT"}
{"t_ms":38466,"seq":77,"slave_index":1,"responder_id":2,"rtt_us":7662,"status":"OK"}
{"t_ms":38958,"seq":78,"slave_index":2,"status":"PING_SENT"}
{"t_ms":39458,"seq":78,"slave_index":2,"responder_id":null,"rtt_us":null,"status":"PING_FAILED"}
{"t_ms":39458,"seq":79,"slave_index":0,"status":"PING_SENT"}
{"t_ms":39460,"seq":79,"slave_index":0,"responder_id":1,"rtt_us":2026,"status":"OK"}
{"t_ms":39958,"seq":80,"slave_index":1,"status":"PING_SENT"}
{"t_ms":39960,"seq":80,"slave_index":1,"responder_id":2,"rtt_us":2211,"status":"OK"}
{"t_ms":40463,"seq":81,"slave_index":2,"status":"PING_SENT"}
{"t_ms":40963,"seq":81,"slave_index":2,"responder_id":null,"rtt_us":null,"status":"PING_FAILED"}
{"t_ms":40963,"seq":82,"slave_index":0,"status":"PING_SENT"}
{"t_ms":40965,"seq":82,"slave_index":0,"responder_id":1,"rtt_us":2253,"status":"OK"}
{"t_ms":41463,"seq":83,"slave_index":1,"status":"PING_SENT"}
{"t_ms":41465,"seq":83,"slave_index":1,"responder_id":2,"rtt_us":2311,"status":"OK"}
{"t_ms":41963,"seq":84,"slave_index":2,"status":"PING_SENT"}
{"t_ms":41971,"seq":84,"slave_index":2,"responder_id":3,"rtt_us":7505,"status":"OK"}
{"t_ms":42468,"seq":85,"slave_index":0,"status":"PING_SENT"}
{"t_ms":42470,"seq":85,"slave_index":0,"responder_id":1,"rtt_us":2000,"status":"OK"}
{"t_ms":42968,"seq":86,"slave_index":1,"status":"PING_SENT"}
{"t_ms":42972,"seq":86,"slave_index":1,"responder_id":2,"rtt_us":3507,"status":"OK"}
{"t_ms":43468,"seq":87,"slave_index":2,"status":"PING_SENT"}
{"t_ms":43968,"seq":87,"slave_index":2,"responder_id":null,"rtt_us":null,"status":"PING_FAILED"}
{"t_ms":43968,"seq":88,"slave_index":0,"status":"PING_SENT"}
{"t_ms":43970,"seq":88,"slave_index":0,"responder_id":1,"rtt_us":1925,"status":"OK"}
{"t_ms":44473,"seq":89,"slave_index":1,"status":"PING_SENT"}
{"t_ms":44476,"seq":89,"slave_index":1,"responder_id":2,"rtt_us":3375,"status":"OK"}
{"t_ms":44973,"seq":90,"slave_index":2,"status":"PING_SENT"}
{"t_ms":44980,"seq":90,"slave_index":2,"responder_id":3,"rtt_us":7015,"status":"OK"}
{"t_ms":45473,"seq":91,"slave_index":0,"status":"PING_SENT"}
{"t_ms":45478,"seq":91,"slave_index":0,"responder_id":1,"rtt_us":4714,"status":"OK"}
{"t_ms":45973,"seq":92,"slave_index":1,"status":"PING_SENT"}
{"t_ms":45975,"seq":92,"slave_index":1,"responder_id":2,"rtt_us":1950,"status":"OK"}
{"t_ms":46478,"seq":93,"slave_index":2,"status":"PING_SENT"}
{"t_ms":46485,"seq":93,"slave_index":2,"responder_id":3,"rtt_us":7071,"status":"OK"}
{"t_ms":46978,"seq":94,"slave_index":0,"status":"PING_SENT"}
{"t_ms":46982,"seq":94,"slave_index":0,"responder_id":1,"rtt_us":3686,"status":"OK"}
{"t_ms":47478,"seq":95,"slave_index":1,"status":"PING_SENT"}
{"t_ms":47485,"seq":95,"slave_index":1,"responder_id":2,"rtt_us":6549,"status":"OK"}
{"t_ms":47978,"seq":96,"slave_index":2,"status":"PING_SENT"}
{"t_ms":47981,"seq":96,"slave_index":2,"responder_id":3,"rtt_us":3020,"status":"OK"}
{"t_ms":48483,"seq":97,"slave_index":0,"status":"PING_SENT"}
{"t_ms":48485,"seq":97,"slave_index":0,"responder_id":1,"rtt_us":1919,"status":"OK"}
{"t_ms":48983,"seq":98,"slave_index":1,"status":"PING_SENT"}
{"t_ms":48985,"seq":98,"slave_index":1,"responder_id":2,"rtt_us":2205,"status":"OK"}
{"t_ms":49483,"seq":99,"slave_index":2,"status":"PING_SENT"}
{"t_ms":49489,"seq":99,"slave_index":2,"responder_id":3,"rtt_us":5568,"status":"OK"}
{"t_ms":49983,"seq":100,"slave_index":0,"status":"PING_SENT"}
{"t_ms":49986,"seq":100,"slave_index":0,"responder_id":1,"rtt_us":3347,"status":"OK"}
{"t_ms":50488,"seq":101,"slave_index":1,"status":"PING_SENT"}
{"t_ms":50492,"seq":101,"slave_index":1,"responder_id":2,"rtt_us":4095,"status":"OK"}
{"t_ms":50988,"seq":102,"slave_index":2,"status":"PING_SENT"}
{"t_ms":50991,"seq":102,"slave_index":2,"responder_id":3,"rtt_us":3203,"status":"OK"}
{"t_ms":51488,"seq":103,"slave_index":0,"status":"PING_SENT"}
{"t_ms":51492,"seq":103,"slave_index":0,"responder_id":1,"rtt_us":4312,"status":"OK"}
{"t_ms":51988,"seq":104,"slave_index":1,"status":"PING_SENT"}
{"t_ms":51990,"seq":104,"slave_index":1,"responder_id":2,"rtt_us":2127,"status":"OK"}
{"t_ms":52493,"seq":105,"slave_index":2,"status":"PING_SENT"}
{"t_ms":52495,"seq":105,"slave_index":2,"responder_id":3,"rtt_us":2172,"status":"OK"}
{"t_ms":52993,"seq":106,"slave_index":0,"status":"PING_SENT"}
{"t_ms":52995,"seq":106,"slave_index":0,"responder_id":1,"rtt_us":2247,"status":"OK"}
{"t_ms":53493,"seq":107,"slave_index":1,"status":"PING_SENT"}
{"t_ms":53496,"seq":107,"slave_index":1,"responder_id":2,"rtt_us":3103,"status":"OK"}
{"t_ms":53993,"seq":108,"slave_index":2,"status":"PING_SENT"}
{"t_ms":53995,"seq":108,"slave_index":2,"responder_id":3,"rtt_us":1795,"status":"OK"}
{"t_ms":54498,"seq":109,"slave_index":0,"status":"PING_SENT"}
{"t_ms":54500,"seq":109,"slave_index":0,"responder_id":1,"rtt_us":2331,"status":"OK"}
{"t_ms":54998,"seq":110,"slave_index":1,"status":"PING_SENT"}
{"t_ms":55000,"seq":110,"slave_index":1,"responder_id":2,"rtt_us":1905,"status":"OK"}
{"t_ms":55498,"seq":111,"slave_index":2,"status":"PING_SENT"}
{"t_ms":55509,"seq":111,"slave_index":2,"responder_id":3,"rtt_us":11108,"status":"OK"}
{"t_ms":55998,"seq":112,"slave_index":0,"status":"PING_SENT"}
{"t_ms":56002,"seq":112,"slave_index":0,"responder_id":1,"rtt_us":3775,"status":"OK"}
{"t_ms":56503,"seq":113,"slave_index":1,"status":"PING_SENT"}
{"t_ms":56505,"seq":113,"slave_index":1,"responder_id":2,"rtt_us":2490,"status":"OK"}
{"t_ms":57003,"seq":114,"slave_index":2,"status":"PING_SENT"}
{"t_ms":57008,"seq":114,"slave_index":2,"responder_id":3,"rtt_us":4873,"status":"OK"}
{"t_ms":57503,"seq":115,"slave_index":0,"status":"PING_SENT"}
{"t_ms":57511,"seq":115,"slave_index":0,"responder_id":1,"rtt_us":8305,"status":"OK"}
{"t_ms":58003,"seq":116,"slave_index":1,"status":"PING_SENT"}
{"t_ms":58013,"seq":116,"slave_index":1,"responder_id":2,"rtt_us":9699,"status":"OK"}
{"t_ms":58508,"seq":117,"slave_index":2,"status":"PING_SENT"}
{"t_ms":58510,"seq":117,"slave_index":2,"responder_id":3,"rtt_us":1835,"status":"OK"}
{"t_ms":59008,"seq":118,"slave_index":0,"status":"PING_SENT"}
{"t_ms":59013,"seq":118,"slave_index":0,"responder_id":1,"rtt_us":5079,"status":"OK"}
{"t_ms":59508,"seq":119,"slave_index":1,"status":"PING_SENT"}
{"t_ms":59512,"seq":119,"slave_index":1,"responder_id":2,"rtt_us":3487,"status":"OK"}
{"t_ms":60008,"seq":120,"slave_index":2,"status":"PING_SENT"}
{"t_ms":60010,"seq":120,"slave_index":2,"responder_id":3,"rtt_us":1808,"status":"OK"}
{"t_ms":60513,"seq":121,"slave_index":0,"status":"PING_SENT"}
{"t_ms":60515,"seq":121,"slave_index":0,"responder_id":1,"rtt_us":1969,"status":"OK"}
{"t_ms":61013,"seq":122,"slave_index":1,"status":"PING_SENT"}
{"t_ms":61017,"seq":122,"slave_index":1,"responder_id":2,"rtt_us":3635,"status":"OK"}
{"t_ms":61513,"seq":123,"slave_index":2,"status":"PING_SENT"}
{"t_ms":61526,"seq":123,"slave_index":2,"responder_id":3,"rtt_us":12759,"status":"OK"}
{"t_ms":62013,"seq":124,"slave_index":0,"status":"PING_SENT"}
{"t_ms":62018,"seq":124,"slave_index":0,"responder_id":1,"rtt_us":5010,"status":"OK"}
{"t_ms":62518,"seq":125,"slave_index":1,"status":"PING_SENT"}
{"t_ms":62520,"seq":125,"slave_index":1,"responder_id":2,"rtt_us":1949,"status":"OK"}
{"t_ms":63018,"seq":126,"slave_index":2,"status":"PING_SENT"}
{"t_ms":63020,"seq":126,"slave_index":2,"responder_id":3,"rtt_us":2109,"status":"OK"}
{"t_ms":63518,"seq":127,"slave_index":0,"status":"PING_SENT"}
{"t_ms":63521,"seq":127,"slave_index":0,"responder_id":1,"rtt_us":3425,"status":"OK"}
{"t_ms":64018,"seq":128,"slave_index":1,"status":"PING_SENT"}
{"t_ms":64022,"seq":128,"slave_index":1,"responder_id":2,"rtt_us":4046,"status":"OK"}
{"t_ms":64523,"seq":129,"slave_index":2,"status":"PING_SENT"}
{"t_ms":64553,"seq":129,"slave_index":2,"responder_id":3,"rtt_us":30422,"status":"OK"}
{"t_ms":65023,"seq":130,"slave_index":0,"status":"PING_SENT"}
{"t_ms":65025,"seq":130,"slave_index":0,"responder_id":1,"rtt_us":2364,"status":"OK"}
{"t_ms":65523,"seq":131,"slave_index":1,"status":"PING_SENT"}
{"t_ms":65528,"seq":131,"slave_index":1,"responder_id":2,"rtt_us":5093,"status":"OK"}
{"t_ms":66023,"seq":132,"slave_index":2,"status":"PING_SENT"}
{"t_ms":66025,"seq":132,"slave_index":2,"responder_id":3,"rtt_us":2247,"status":"OK"}
{"t_ms":66528,"seq":133,"slave_index":0,"status":"PING_SENT"}
{"t_ms":66530,"seq":133,"slave_index":0,"responder_id":1,"rtt_us":2307,"status":"OK"}
{"t_ms":67028,"seq":134,"slave_index":1,"status":"PING_SENT"}
{"t_ms":67031,"seq":134,"slave_index":1,"responder_id":2,"rtt_us":2498,"status":"OK"}
{"t_ms":67528,"seq":135,"slave_index":2,"status":"PING_SENT"}
{"t_ms":67534,"seq":135,"slave_index":2,"responder_id":3,"rtt_us":5906,"status":"OK"}
{"t_ms":68028,"seq":136,"slave_index":0,"status":"PING_SENT"}
{"t_ms":68037,"seq":136,"slave_index":0,"responder_id":1,"rtt_us":9188,"status":"OK"}
{"t_ms":68533,"seq":137,"slave_index":1,"status":"PING_SENT"}
{"t_ms":68537,"seq":137,"slave_index":1,"responder_id":2,"rtt_us":3507,"status":"OK"}
{"t_ms":69033,"seq":138,"slave_index":2,"status":"PING_SENT"}
{"t_ms":69035,"seq":138,"slave_index":2,"responder_id":3,"rtt_us":2151,"status":"OK"}
{"t_ms":69533,"seq":139,"slave_index":0,"status":"PING_SENT"}
{"t_ms":69536,"seq":139,"slave_index":0,"responder_id":1,"rtt_us":3372,"status":"OK"}
{"t_ms":70033,"seq":140,"slave_index":1,"status":"PING_SENT"}
{"t_ms":70035,"seq":140,"slave_index":1,"responder_id":2,"rtt_us":2075,"status":"OK"}
{"t_ms":70538,"seq":141,"slave_index":2,"status":"PING_SENT"}
{"t_ms":70540,"seq":141,"slave_index":2,"responder_id":3,"rtt_us":1787,"status":"OK"}
{"t_ms":71038,"seq":142,"slave_index":0,"status":"PING_SENT"}
{"t_ms":71040,"seq":142,"slave_index":0,"responder_id":1,"rtt_us":1894,"status":"OK"}
{"t_ms":71538,"seq":143,"slave_index":1,"status":"PING_SENT"}
{"t_ms":71541,"seq":143,"slave_index":1,"responder_id":2,"rtt_us":2706,"status":"OK"}
{"t_ms":72038,"seq":144,"slave_index":2,"status":"PING_SENT"}
{"t_ms":72040,"seq":144,"slave_index":2,"responder_id":3,"rtt_us":1990,"status":"OK"}
{"t_ms":72543,"seq":145,"slave_index":0,"status":"PING_SENT"}
{"t_ms":72548,"seq":145,"slave_index":0,"responder_id":1,"rtt_us":5211,"status":"OK"}
{"t_ms":73043,"seq":146,"slave_index":1,"status":"PING_SENT"}
{"t_ms":73045,"seq":146,"slave_index":1,"responder_id":2,"rtt_us":2128,"status":"OK"}
{"t_ms":73543,"seq":147,"slave_index":2,"status":"PING_SENT"}
{"t_ms":73546,"seq":147,"slave_index":2,"responder_id":3,"rtt_us":2506,"status":"OK"}
{"t_ms":74043,"seq":148,"slave_index":0,"status":"PING_SENT"}
{"t_ms":74045,"seq":148,"slave_index":0,"responder_id":1,"rtt_us":1960,"status":"OK"}
{"t_ms":74548,"seq":149,"slave_index":1,"status":"PING_SENT"}
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

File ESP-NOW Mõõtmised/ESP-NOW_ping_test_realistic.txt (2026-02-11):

--- Session start 2026-01-07T14:50:26 ---
{"t_ms":511632,"seq":1021,"slave_index":0,"status":"PING_SENT"}
{"t_ms":511639,"seq":1021,"slave_index":0,"responder_id":1,"rtt_us":6502,"status":"OK"}
{"t_ms":512132,"seq":1022,"slave_index":1,"status":"PING_SENT"}
{"t_ms":512134,"seq":1022,"slave_index":1,"responder_id":2,"rtt_us":2105,"status":"OK"}
{"t_ms":512632,"seq":1023,"slave_index":2,"status":"PING_SENT"}
{"t_ms":512635,"seq":1023,"slave_index":2,"responder_id":3,"rtt_us":2519,"status":"OK"}
{"t_ms":513132,"seq":1024,"slave_index":0,"status":"PING_SENT"}
{"t_ms":513134,"seq":1024,"slave_index":0,"responder_id":1,"rtt_us":1957,"status":"OK"}
{"t_ms":513637,"seq":1025,"slave_index":1,"status":"PING_SENT"}
{"t_ms":513639,"seq":1025,"slave_index":1,"responder_id":2,"rtt_us":1907,"status":"OK"}
{"t_ms":514137,"seq":1026,"slave_index":2,"status":"PING_SENT"}
{"t_ms":514157,"seq":1026,"slave_index":2,"responder_id":3,"rtt_us":19897,"status":"OK"}
{"t_ms":514637,"seq":1027,"slave_index":0,"status":"PING_SENT"}
{"t_ms":514639,"seq":1027,"slave_index":0,"responder_id":1,"rtt_us":2428,"status":"OK"}
{"t_ms":515137,"seq":1028,"slave_index":1,"status":"PING_SENT"}
{"t_ms":515141,"seq":1028,"slave_index":1,"responder_id":2,"rtt_us":3828,"status":"OK"}
{"t_ms":515642,"seq":1029,"slave_index":2,"status":"PING_SENT"}
{"t_ms":515645,"seq":1029,"slave_index":2,"responder_id":3,"rtt_us":3249,"status":"OK"}
{"t_ms":516142,"seq":1030,"slave_index":0,"status":"PING_SENT"}
{"t_ms":516144,"seq":1030,"slave_index":0,"responder_id":1,"rtt_us":2065,"status":"OK"}
{"t_ms":516642,"seq":1031,"slave_index":1,"status":"PING_SENT"}
{"t_ms":516644,"seq":1031,"slave_index":1,"responder_id":2,"rtt_us":2196,"status":"OK"}
{"t_ms":517142,"seq":1032,"slave_index":2,"status":"PING_SENT"}
{"t_ms":517146,"seq":1032,"slave_index":2,"responder_id":3,"rtt_us":3806,"status":"OK"}
{"t_ms":517647,"seq":1033,"slave_index":0,"status":"PING_SENT"}
{"t_ms":517652,"seq":1033,"slave_index":0,"responder_id":1,"rtt_us":4869,"status":"OK"}
{"t_ms":518147,"seq":1034,"slave_index":1,"status":"PING_SENT"}
{"t_ms":518149,"seq":1034,"slave_index":1,"responder_id":2,"rtt_us":1935,"status":"OK"}
{"t_ms":518647,"seq":1035,"slave_index":2,"status":"PING_SENT"}
{"t_ms":518649,"seq":1035,"slave_index":2,"responder_id":3,"rtt_us":1908,"status":"OK"}
{"t_ms":519147,"seq":1036,"slave_index":0,"status":"PING_SENT"}
{"t_ms":519153,"seq":1036,"slave_index":0,"responder_id":1,"rtt_us":5847,"status":"OK"}
{"t_ms":519652,"seq":1037,"slave_index":1,"status":"PING_SENT"}
{"t_ms":519655,"seq":1037,"slave_index":1,"responder_id":2,"rtt_us":2583,"status":"OK"}
{"t_ms":520152,"seq":1038,"slave_index":2,"status":"PING_SENT"}
{"t_ms":520154,"seq":1038,"slave_index":2,"responder_id":3,"rtt_us":2003,"status":"OK"}
{"t_ms":520652,"seq":1039,"slave_index":0,"status":"PING_SENT"}
{"t_ms":520654,"seq":1039,"slave_index":0,"responder_id":1,"rtt_us":1948,"status":"OK"}
{"t_ms":521152,"seq":1040,"slave_index":1,"status":"PING_SENT"}
{"t_ms":521154,"seq":1040,"slave_index":1,"responder_id":2,"rtt_us":2444,"status":"OK"}
{"t_ms":521657,"seq":1041,"slave_index":2,"status":"PING_SENT"}
{"t_ms":521668,"seq":1041,"slave_index":2,"responder_id":3,"rtt_us":10562,"status":"OK"}
{"t_ms":522157,"seq":1042,"slave_index":0,"status":"PING_SENT"}
{"t_ms":522159,"seq":1042,"slave_index":0,"responder_id":1,"rtt_us":1950,"status":"OK"}
{"t_ms":522657,"seq":1043,"slave_index":1,"status":"PING_SENT"}
{"t_ms":522659,"seq":1043,"slave_index":1,"responder_id":2,"rtt_us":1923,"status":"OK"}
{"t_ms":523157,"seq":1044,"slave_index":2,"status":"PING_SENT"}
{"t_ms":523162,"seq":1044,"slave_index":2,"responder_id":3,"rtt_us":4584,"status":"OK"}
{"t_ms":523662,"seq":1045,"slave_index":0,"status":"PING_SENT"}
{"t_ms":523664,"seq":1045,"slave_index":0,"responder_id":1,"rtt_us":2418,"status":"OK"}
{"t_ms":524162,"seq":1046,"slave_index":1,"status":"PING_SENT"}
{"t_ms":524172,"seq":1046,"slave_index":1,"responder_id":2,"rtt_us":10471,"status":"OK"}
{"t_ms":524662,"seq":1047,"slave_index":2,"status":"PING_SENT"}
{"t_ms":524666,"seq":1047,"slave_index":2,"responder_id":3,"rtt_us":3746,"status":"OK"}
{"t_ms":525162,"seq":1048,"slave_index":0,"status":"PING_SENT"}
{"t_ms":525164,"seq":1048,"slave_index":0,"responder_id":1,"rtt_us":1956,"status":"OK"}
{"t_ms":525667,"seq":1049,"slave_index":1,"status":"PING_SENT"}
{"t_ms":525669,"seq":1049,"slave_index":1,"responder_id":2,"rtt_us":2047,"status":"OK"}
{"t_ms":526167,"seq":1050,"slave_index":2,"status":"PING_SENT"}
{"t_ms":526169,"seq":1050,"slave_index":2,"responder_id":3,"rtt_us":1993,"status":"OK"}
{"t_ms":526667,"seq":1051,"slave_index":0,"status":"PING_SENT"}
{"t_ms":526669,"seq":1051,"slave_index":0,"responder_id":1,"rtt_us":2232,"status":"OK"}
{"t_ms":527167,"seq":1052,"slave_index":1,"status":"PING_SENT"}
{"t_ms":527169,"seq":1052,"slave_index":1,"responder_id":2,"rtt_us":1926,"status":"OK"}
{"t_ms":527672,"seq":1053,"slave_index":2,"status":"PING_SENT"}
{"t_ms":527676,"seq":1053,"slave_index":2,"responder_id":3,"rtt_us":4155,"status":"OK"}
{"t_ms":528172,"seq":1054,"slave_index":0,"status":"PING_SENT"}
{"t_ms":528177,"seq":1054,"slave_index":0,"responder_id":1,"rtt_us":4924,"status":"OK"}
{"t_ms":528672,"seq":1055,"slave_index":1,"status":"PING_SENT"}
{"t_ms":528678,"seq":1055,"slave_index":1,"responder_id":2,"rtt_us":5485,"status":"OK"}
{"t_ms":529172,"seq":1056,"slave_index":2,"status":"PING_SENT"}
{"t_ms":529174,"seq":1056,"slave_index":2,"responder_id":3,"rtt_us":1810,"status":"OK"}
{"t_ms":529677,"seq":1057,"slave_index":0,"status":"PING_SENT"}
{"t_ms":529679,"seq":1057,"slave_index":0,"responder_id":1,"rtt_us":1955,"status":"OK"}
{"t_ms":530177,"seq":1058,"slave_index":1,"status":"PING_SENT"}
{"t_ms":530179,"seq":1058,"slave_index":1,"responder_id":2,"rtt_us":1954,"status":"OK"}
{"t_ms":530677,"seq":1059,"slave_index":2,"status":"PING_SENT"}
{"t_ms":530679,"seq":1059,"slave_index":2,"responder_id":3,"rtt_us":2025,"status":"OK"}
{"t_ms":531177,"seq":1060,"slave_index":0,"status":"PING_SENT"}
{"t_ms":531179,"seq":1060,"slave_index":0,"responder_id":1,"rtt_us":1940,"status":"OK"}
{"t_ms":531682,"seq":1061,"slave_index":1,"status":"PING_SENT"}
{"t_ms":531686,"seq":1061,"slave_index":1,"responder_id":2,"rtt_us":3561,"status":"OK"}
{"t_ms":532182,"seq":1062,"slave_index":2,"status":"PING_SENT"}
{"t_ms":532184,"seq":1062,"slave_index":2,"responder_id":3,"rtt_us":2235,"status":"OK"}
{"t_ms":532682,"seq":1063,"slave_index":0,"status":"PING_SENT"}
{"t_ms":532684,"seq":1063,"slave_index":0,"responder_id":1,"rtt_us":2211,"status":"OK"}
{"t_ms":533182,"seq":1064,"slave_index":1,"status":"PING_SENT"}
{"t_ms":533188,"seq":1064,"slave_index":1,"responder_id":2,"rtt_us":6183,"status":"OK"}
{"t_ms":533687,"seq":1065,"slave_index":2,"status":"PING_SENT"}
{"t_ms":533698,"seq":1065,"slave_index":2,"responder_id":3,"rtt_us":10691,"status":"OK"}
{"t_ms":534187,"seq":1066,"slave_index":0,"status":"PING_SENT"}
{"t_ms":534189,"seq":1066,"slave_index":0,"responder_id":1,"rtt_us":1977,"status":"OK"}
{"t_ms":534687,"seq":1067,"slave_index":1,"status":"PING_SENT"}
{"t_ms":534690,"seq":1067,"slave_index":1,"responder_id":2,"rtt_us":2754,"status":"OK"}
{"t_ms":535187,"seq":1068,"slave_index":2,"status":"PING_SENT"}
{"t_ms":535189,"seq":1068,"slave_index":2,"responder_id":3,"rtt_us":1782,"status":"OK"}
{"t_ms":535692,"seq":1069,"slave_index":0,"status":"PING_SENT"}
{"t_ms":535694,"seq":1069,"slave_index":0,"responder_id":1,"rtt_us":2349,"status":"OK"}
{"t_ms":536192,"seq":1070,"slave_index":1,"status":"PING_SENT"}
{"t_ms":536196,"seq":1070,"slave_index":1,"responder_id":2,"rtt_us":3581,"status":"OK"}
{"t_ms":536692,"seq":1071,"slave_index":2,"status":"PING_SENT"}
{"t_ms":536697,"seq":1071,"slave_index":2,"responder_id":3,"rtt_us":4736,"status":"OK"}
{"t_ms":537192,"seq":1072,"slave_index":0,"status":"PING_SENT"}
{"t_ms":537195,"seq":1072,"slave_index":0,"responder_id":1,"rtt_us":3353,"status":"OK"}
{"t_ms":537697,"seq":1073,"slave_index":1,"status":"PING_SENT"}
{"t_ms":537703,"seq":1073,"slave_index":1,"responder_id":2,"rtt_us":5521,"status":"OK"}
{"t_ms":538197,"seq":1074,"slave_index":2,"status":"PING_SENT"}
{"t_ms":538199,"seq":1074,"slave_index":2,"responder_id":3,"rtt_us":1778,"status":"OK"}
{"t_ms":538697,"seq":1075,"slave_index":0,"status":"PING_SENT"}
{"t_ms":538699,"seq":1075,"slave_index":0,"responder_id":1,"rtt_us":1931,"status":"OK"}
{"t_ms":539197,"seq":1076,"slave_index":1,"status":"PING_SENT"}
{"t_ms":539199,"seq":1076,"slave_index":1,"responder_id":2,"rtt_us":1942,"status":"OK"}
{"t_ms":539702,"seq":1077,"slave_index":2,"status":"PING_SENT"}
{"t_ms":539706,"seq":1077,"slave_index":2,"responder_id":3,"rtt_us":3728,"status":"OK"}
{"t_ms":540202,"seq":1078,"slave_index":0,"status":"PING_SENT"}
{"t_ms":540204,"seq":1078,"slave_index":0,"responder_id":1,"rtt_us":2079,"status":"OK"}
{"t_ms":540702,"seq":1079,"slave_index":1,"status":"PING_SENT"}
{"t_ms":540705,"seq":1079,"slave_index":1,"responder_id":2,"rtt_us":2799,"status":"OK"}
{"t_ms":541202,"seq":1080,"slave_index":2,"status":"PING_SENT"}
{"t_ms":541204,"seq":1080,"slave_index":2,"responder_id":3,"rtt_us":2189,"status":"OK"}
{"t_ms":541707,"seq":1081,"slave_index":0,"status":"PING_SENT"}
{"t_ms":541709,"seq":1081,"slave_index":0,"responder_id":1,"rtt_us":1956,"status":"OK"}
{"t_ms":542207,"seq":1082,"slave_index":1,"status":"PING_SENT"}
{"t_ms":542212,"seq":1082,"slave_index":1,"responder_id":2,"rtt_us":4920,"status":"OK"}
{"t_ms":542707,"seq":1083,"slave_index":2,"status":"PING_SENT"}
{"t_ms":542709,"seq":1083,"slave_index":2,"responder_id":3,"rtt_us":1769,"status":"OK"}
{"t_ms":543207,"seq":1084,"slave_index":0,"status":"PING_SENT"}
{"t_ms":543210,"seq":1084,"slave_index":0,"responder_id":1,"rtt_us":2578,"status":"OK"}
{"t_ms":543712,"seq":1085,"slave_index":1,"status":"PING_SENT"}
{"t_ms":543714,"seq":1085,"slave_index":1,"responder_id":2,"rtt_us":2163,"status":"OK"}
{"t_ms":544212,"seq":1086,"slave_index":2,"status":"PING_SENT"}
{"t_ms":544214,"seq":1086,"slave_index":2,"responder_id":3,"rtt_us":1755,"status":"OK"}
{"t_ms":544712,"seq":1087,"slave_index":0,"status":"PING_SENT"}
{"t_ms":544714,"seq":1087,"slave_index":0,"responder_id":1,"rtt_us":2009,"status":"OK"}
{"t_ms":545212,"seq":1088,"slave_index":1,"status":"PING_SENT"}
{"t_ms":545217,"seq":1088,"slave_index":1,"responder_id":2,"rtt_us":4832,"status":"OK"}
{"t_ms":545717,"seq":1089,"slave_index":2,"status":"PING_SENT"}
{"t_ms":545728,"seq":1089,"slave_index":2,"responder_id":3,"rtt_us":11048,"status":"OK"}
{"t_ms":546217,"seq":1090,"slave_index":0,"status":"PING_SENT"}
{"t_ms":546219,"seq":1090,"slave_index":0,"responder_id":1,"rtt_us":1915,"status":"OK"}
{"t_ms":546717,"seq":1091,"slave_index":1,"status":"PING_SENT"}
{"t_ms":546722,"seq":1091,"slave_index":1,"responder_id":2,"rtt_us":5066,"status":"OK"}
{"t_ms":547217,"seq":1092,"slave_index":2,"status":"PING_SENT"}
{"t_ms":547221,"seq":1092,"slave_index":2,"responder_id":3,"rtt_us":3863,"status":"OK"}
{"t_ms":547722,"seq":1093,"slave_index":0,"status":"PING_SENT"}
{"t_ms":547724,"seq":1093,"slave_index":0,"responder_id":1,"rtt_us":1920,"status":"OK"}
{"t_ms":548222,"seq":1094,"slave_index":1,"status":"PING_SENT"}
{"t_ms":548228,"seq":1094,"slave_index":1,"responder_id":2,"rtt_us":5875,"status":"OK"}
{"t_ms":548722,"seq":1095,"slave_index":2,"status":"PING_SENT"}
{"t_ms":548725,"seq":1095,"slave_index":2,"responder_id":3,"rtt_us":3326,"status":"OK"}
{"t_ms":549222,"seq":1096,"slave_index":0,"status":"PING_SENT"}
{"t_ms":549224,"seq":1096,"slave_index":0,"responder_id":1,"rtt_us":1930,"status":"OK"}
{"t_ms":549727,"seq":1097,"slave_index":1,"status":"PING_SENT"}
{"t_ms":549730,"seq":1097,"slave_index":1,"responder_id":2,"rtt_us":3434,"status":"OK"}
{"t_ms":550227,"seq":1098,"slave_index":2,"status":"PING_SENT"}
{"t_ms":550230,"seq":1098,"slave_index":2,"responder_id":3,"rtt_us":2942,"status":"OK"}
{"t_ms":550727,"seq":1099,"slave_index":0,"status":"PING_SENT"}
{"t_ms":550729,"seq":1099,"slave_index":0,"responder_id":1,"rtt_us":1946,"status":"OK"}
{"t_ms":551227,"seq":1100,"slave_index":1,"status":"PING_SENT"}
{"t_ms":551230,"seq":1100,"slave_index":1,"responder_id":2,"rtt_us":3400,"status":"OK"}
{"t_ms":551732,"seq":1101,"slave_index":2,"status":"PING_SENT"}
{"t_ms":551735,"seq":1101,"slave_index":2,"responder_id":3,"rtt_us":3137,"status":"OK"}
{"t_ms":552232,"seq":1102,"slave_index":0,"status":"PING_SENT"}
{"t_ms":552234,"seq":1102,"slave_index":0,"responder_id":1,"rtt_us":1935,"status":"OK"}
{"t_ms":552732,"seq":1103,"slave_index":1,"status":"PING_SENT"}
{"t_ms":552740,"seq":1103,"slave_index":1,"responder_id":2,"rtt_us":8324,"status":"OK"}
{"t_ms":553232,"seq":1104,"slave_index":2,"status":"PING_SENT"}
{"t_ms":553234,"seq":1104,"slave_index":2,"responder_id":3,"rtt_us":1799,"status":"OK"}
{"t_ms":553737,"seq":1105,"slave_index":0,"status":"PING_SENT"}
{"t_ms":553740,"seq":1105,"slave_index":0,"responder_id":1,"rtt_us":2837,"status":"OK"}
{"t_ms":554237,"seq":1106,"slave_index":1,"status":"PING_SENT"}
{"t_ms":554244,"seq":1106,"slave_index":1,"responder_id":2,"rtt_us":7284,"status":"OK"}
{"t_ms":554737,"seq":1107,"slave_index":2,"status":"PING_SENT"}
{"t_ms":554742,"seq":1107,"slave_index":2,"responder_id":3,"rtt_us":5394,"status":"OK"}
{"t_ms":555237,"seq":1108,"slave_index":0,"status":"PING_SENT"}
{"t_ms":555239,"seq":1108,"slave_index":0,"responder_id":1,"rtt_us":2297,"status":"OK"}
{"t_ms":555742,"seq":1109,"slave_index":1,"status":"PING_SENT"}
{"t_ms":555746,"seq":1109,"slave_index":1,"responder_id":2,"rtt_us":3565,"status":"OK"}
{"t_ms":556242,"seq":1110,"slave_index":2,"status":"PING_SENT"}
{"t_ms":556244,"seq":1110,"slave_index":2,"responder_id":3,"rtt_us":2065,"status":"OK"}
{"t_ms":556742,"seq":1111,"slave_index":0,"status":"PING_SENT"}
{"t_ms":556744,"seq":1111,"slave_index":0,"responder_id":1,"rtt_us":1947,"status":"OK"}
{"t_ms":557242,"seq":1112,"slave_index":1,"status":"PING_SENT"}
{"t_ms":557247,"seq":1112,"slave_index":1,"responder_id":2,"rtt_us":5066,"status":"OK"}
{"t_ms":557747,"seq":1113,"slave_index":2,"status":"PING_SENT"}
{"t_ms":557759,"seq":1113,"slave_index":2,"responder_id":3,"rtt_us":11846,"status":"OK"}
{"t_ms":558247,"seq":1114,"slave_index":0,"status":"PING_SENT"}
{"t_ms":558250,"seq":1114,"slave_index":0,"responder_id":1,"rtt_us":2662,"status":"OK"}
{"t_ms":558747,"seq":1115,"slave_index":1,"status":"PING_SENT"}
{"t_ms":558749,"seq":1115,"slave_index":1,"responder_id":2,"rtt_us":1948,"status":"OK"}
{"t_ms":559247,"seq":1116,"slave_index":2,"status":"PING_SENT"}
{"t_ms":559249,"seq":1116,"slave_index":2,"responder_id":3,"rtt_us":1815,"status":"OK"}
{"t_ms":559752,"seq":1117,"slave_index":0,"status":"PING_SENT"}
{"t_ms":559754,"seq":1117,"slave_index":0,"responder_id":1,"rtt_us":2117,"status":"OK"}
{"t_ms":560252,"seq":1118,"slave_index":1,"status":"PING_SENT"}
{"t_ms":560254,"seq":1118,"slave_index":1,"responder_id":2,"rtt_us":2030,"status":"OK"}
{"t_ms":560752,"seq":1119,"slave_index":2,"status":"PING_SENT"}
{"t_ms":560754,"seq":1119,"slave_index":2,"responder_id":3,"rtt_us":1779,"status":"OK"}
{"t_ms":561252,"seq":1120,"slave_index":0,"status":"PING_SENT"}
{"t_ms":561254,"seq":1120,"slave_index":0,"responder_id":1,"rtt_us":1931,"status":"OK"}
{"t_ms":561757,"seq":1121,"slave_index":1,"status":"PING_SENT"}
{"t_ms":561759,"seq":1121,"slave_index":1,"responder_id":2,"rtt_us":1924,"status":"OK"}
{"t_ms":562257,"seq":1122,"slave_index":2,"status":"PING_SENT"}
{"t_ms":562262,"seq":1122,"slave_index":2,"responder_id":3,"rtt_us":5309,"status":"OK"}
{"t_ms":562757,"seq":1123,"slave_index":0,"status":"PING_SENT"}
{"t_ms":562759,"seq":1123,"slave_index":0,"responder_id":1,"rtt_us":2061,"status":"OK"}
{"t_ms":563257,"seq":1124,"slave_index":1,"status":"PING_SENT"}
{"t_ms":563259,"seq":1124,"slave_index":1,"responder_id":2,"rtt_us":1927,"status":"OK"}
{"t_ms":563762,"seq":1125,"slave_index":2,"status":"PING_SENT"}
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

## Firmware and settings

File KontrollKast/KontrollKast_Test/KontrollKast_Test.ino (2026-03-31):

/*
 * KontrollKast_Test.ino — Hardware test sketch for KontrollKast PCB (ESP32-S3)
 *
 * Tests:
 *   - ST7796 320×480 SPI display (Arduino_GFX_Library)
 *   - FT6336U capacitive touch (I2C, direct register read)
 *   - 3× illuminated push-buttons + backlight MOSFETs
 *   - 433 MHz reception (RXB6 on GPIO 1, RCSwitch library)
 *   - RS-485 half-duplex (SN65HVD72, GPIO 4/5/6, ArduinoJson)
 *   - On-screen touch buttons: Blink All, Stop All, Ping All, 433 Pair
 *
 * Serial monitor: 115200 baud
 * Board: ESP32S3 Dev Module
 *
 * Required libraries:
 *   - Arduino_GFX_Library (moononournation)
 *   - ArduinoJson v6
 *   - RCSwitch (by sui77)
 */

#include <Wire.h>
#include <Arduino_GFX_Library.h>
#include <RCSwitch.h>
#include <ArduinoJson.h>
#include <HardwareSerial.h>

// ─── Pin definitions ──────────────────────────────────────────────────────────
#define PIN_433_DATA    1   // RXB6 data
#define PIN_LCD_BL      3   // Backlight
#define PIN_RS485_MODE  4   // DE/RE: HIGH=TX, LOW=RX
#define PIN_RS485_TX    5
#define PIN_RS485_RX    6
#define TFT_SCLK        8
#define TFT_MISO        9
#define PIN_TOUCH_SCL  10
#define PIN_TOUCH_RST  11
#define PIN_TOUCH_SDA  12
#define PIN_TOUCH_INT  13
#define TFT_CS         15
#define TFT_RST        16
#define TFT_DC         17
#define TFT_MOSI       18
#define PIN_BTN1_BL    21   // Button 1 backlight MOSFET
#define PIN_BTN2_BL    35   // Button 2 backlight MOSFET
#define PIN_BTN2_IN    36   // Button 2 input (active LOW)
#define PIN_BTN3_BL    39   // Button 3 backlight MOSFET
#define PIN_BTN3_IN    40   // Button 3 input (active LOW)
#define PIN_BTN1_IN    48   // Button 1 input (active LOW)

// ─── FT6336U touch (I2C address 0x38) ────────────────────────────────────────
#define FT6336U_ADDR  0x38

// ─── RS-485 ───────────────────────────────────────────────────────────────────
HardwareSerial RS485(1);    // UART1
#define RS485_BAUD  115200

// ─── Display (Arduino_GFX_Library) ───────────────────────────────────────────
Arduino_DataBus *bus = new Arduino_ESP32SPI(
    TFT_DC, TFT_CS, TFT_SCLK, TFT_MOSI, TFT_MISO
);
Arduino_GFX *gfx = new Arduino_ST7796(
    bus,
    TFT_RST,
    0,      // native rotation for init
    true,   // IPS
    320,    // native width
    480     // native height
);

#define TFT_W 320
#define TFT_H 480

// Colour palette
#define C_BG      0x0000        // black
#define C_HEADER  0x1A3A        // dark blue-green
#define C_TEXT    0xFFFF        // white
#define C_GREEN   0x07E0
#define C_RED     0xF800
#define C_YELLOW  0xFFE0
#define C_ORANGE  0xFD00
#define C_GRAY    0x7BEF

// ─── 433 MHz ──────────────────────────────────────────────────────────────────
RCSwitch rf433;
bool pairingMode433 = false;

// ─── Button state ─────────────────────────────────────────────────────────────
bool btnState[3]  = {false, false, false};
bool btnBl[3]     = {false, false, false};
const uint8_t BTN_IN[3]  = {PIN_BTN1_IN,  PIN_BTN2_IN,  PIN_BTN3_IN};
const uint8_t BTN_BL[3]  = {PIN_BTN1_BL,  PIN_BTN2_BL,  PIN_BTN3_BL};

// ─── On-screen button layout ──────────────────────────────────────────────────
struct ScreenBtn {
    int16_t x, y, w, h;
    const char *label;
    uint16_t color;
};

static const ScreenBtn screenBtns[] = {
    {  10, 310, 140, 50, "Blink All",  C_ORANGE },
    { 170, 310, 140, 50, "Stop All",   C_RED    },
    {  10, 370, 140, 50, "Ping All",   C_GREEN  },
    { 170, 370, 140, 50, "433 Pair",   C_YELLOW },
    {  10, 430, 300, 40, "RS485 Ping", C_GRAY   },
};
static const int NUM_SCREEN_BTNS = 5;

// ─── Forward declarations ─────────────────────────────────────────────────────
void touchBegin();
bool touchRead(int16_t &x, int16_t &y);
void drawUI();
void redrawLog();
void drawScreenBtns();
void redrawBtnStatus();
void rs485Send(const String &json);
void sendRS485Ping();
void handleRS485();
void handleScreenTouch(int16_t x, int16_t y);
void sendBlinkAll();
void sendStopAll();
void sendPingAll();
void enter433Pairing();

// ─── Status log (last 6 lines) ────────────────────────────────────────────────
#define LOG_LINES 6
String logLines[LOG_LINES];
int    logHead = 0;

void logAdd(const String &s) {
    logLines[logHead] = s;
    logHead = (logHead + 1) % LOG_LINES;
    Serial.println(s);
    redrawLog();
}

// ─── Setup ────────────────────────────────────────────────────────────────────
void setup() {
    Serial.begin(115200);
    delay(300);
    Serial.println("\n=== KontrollKast Test Sketch ===");

    // ── Physical buttons & backlights ─────────────────────────────────────────
    for (int i = 0; i < 3; i++) {
        pinMode(BTN_IN[i], INPUT_PULLUP);
        pinMode(BTN_BL[i], OUTPUT);
        digitalWrite(BTN_BL[i], LOW);
    }

    // ── RS-485 ────────────────────────────────────────────────────────────────
    pinMode(PIN_RS485_MODE, OUTPUT);
    digitalWrite(PIN_RS485_MODE, LOW);  // receive mode
    RS485.begin(RS485_BAUD, SERIAL_8N1, PIN_RS485_RX, PIN_RS485_TX);
    Serial.println("RS-485 ready");

    // ── 433 MHz ───────────────────────────────────────────────────────────────
    rf433.enableReceive(PIN_433_DATA);
    Serial.println("433 MHz ready");

    // ── Display ───────────────────────────────────────────────────────────────
    pinMode(PIN_LCD_BL, OUTPUT);
    digitalWrite(PIN_LCD_BL, HIGH);

    if (!gfx->begin()) {
        Serial.println("ERROR: Display init failed — check wiring");
        while (1) delay(100);
    }
    gfx->setRotation(0);   // portrait, USB at bottom
    gfx->fillScreen(C_BG);
    Serial.println("Display ready");

    // ── Touch ─────────────────────────────────────────────────────────────────
    touchBegin();
    Serial.println("Touch ready");

    // ── Draw UI ───────────────────────────────────────────────────────────────
    drawUI();
    logAdd("System started");

    // ── Send initial ping broadcast ───────────────────────────────────────────
    delay(500);
    sendPingAll();
}

// ─── Loop ─────────────────────────────────────────────────────────────────────
void loop() {
    // ── RS-485 incoming ───────────────────────────────────────────────────────
    handleRS485();

    // ── 433 MHz reception ─────────────────────────────────────────────────────
    if (rf433.available()) {
        unsigned long code = rf433.getReceivedValue();
        int bits           = rf433.getReceivedBitlength();
        rf433.resetAvailable();

        String msg = "433RX code=" + String(code) + " bits=" + String(bits);
        logAdd(msg);

        if (pairingMode433) {
            logAdd("Paired: " + String(code));
            pairingMode433 = false;
            for (int i = 0; i < 3; i++) {
                digitalWrite(BTN_BL[i], btnBl[i] ? HIGH : LOW);
            }
        }
    }

    // ── Physical button handling ───────────────────────────────────────────────
    for (int i = 0; i < 3; i++) {
        bool pressed = !digitalRead(BTN_IN[i]);  // active LOW
        if (pressed && !btnState[i]) {
            btnState[i] = true;
            btnBl[i]    = !btnBl[i];
            digitalWrite(BTN_BL[i], btnBl[i] ? HIGH : LOW);
            String msg = "Button " + String(i+1) + (btnBl[i] ? " ON" : " OFF");
            logAdd(msg);
            redrawBtnStatus();

            if (i == 0) sendBlinkAll();
            if (i == 1) sendStopAll();
            if (i == 2) sendPingAll();
        }
        if (!pressed) btnState[i] = false;
    }

    // ── Touch handling ────────────────────────────────────────────────────────
    int16_t tx, ty;
    if (touchRead(tx, ty)) {
        char buf[32];
        gfx->fillRect(10, 270, 300, 30, C_BG);
        gfx->setTextColor(C_GRAY, C_BG);
        gfx->setTextSize(1);
        gfx->setCursor(10, 275);
        snprintf(buf, sizeof(buf), "Touch: X=%3d Y=%3d", tx, ty);
        gfx->print(buf);

        handleScreenTouch(tx, ty);
        delay(80);  // simple debounce
    }

    // ── Periodic ping every 5 s ───────────────────────────────────────────────
    static uint32_t lastPingMs = 0;
    if (millis() - lastPingMs >= 5000) {
        lastPingMs = millis();
        sendPingAll();
    }
}

// ─── Touch (FT6336U, direct I2C) ─────────────────────────────────────────────
void touchBegin() {
    Wire.begin(PIN_TOUCH_SDA, PIN_TOUCH_SCL);
    pinMode(PIN_TOUCH_RST, OUTPUT);
    digitalWrite(PIN_TOUCH_RST, LOW);  delay(10);
    digitalWrite(PIN_TOUCH_RST, HIGH); delay(100);
    pinMode(PIN_TOUCH_INT, INPUT);
}

bool touchRead(int16_t &x, int16_t &y) {
    Wire.beginTransmission(FT6336U_ADDR);
    Wire.write(0x02);
    Wire.endTransmission(false);
    Wire.requestFrom(FT6336U_ADDR, 5);

    if (Wire.available() < 5) return false;
    uint8_t touches = Wire.read();
    uint8_t xh      = Wire.read();
    uint8_t xl      = Wire.read();
    uint8_t yh      = Wire.read();
    uint8_t yl      = Wire.read();

    if ((touches & 0x0F) == 0) return false;

    x = (int16_t)(((xh & 0x0F) << 8) | xl);
    y = (int16_t)(((yh & 0x0F) << 8) | yl);
    return true;
}

// ─── Display helpers ──────────────────────────────────────────────────────────
void drawUI() {
    gfx->fillScreen(C_BG);

    // Header
    gfx->fillRect(0, 0, TFT_W, 45, C_HEADER);
    gfx->setTextColor(C_TEXT, C_HEADER);
    gfx->setTextSize(2);
    gfx->setCursor(10, 12);
    gfx->print("KontrollKast TEST");

    // Section labels
    gfx->setTextColor(C_GRAY, C_BG);
    gfx->setTextSize(1);
    gfx->setCursor(10, 52);
    gfx->print("Physical buttons:");

    gfx->setCursor(10, 140);
    gfx->print("RS-485 / ESP-NOW log:");

    gfx->setCursor(10, 265);
    gfx->print("Touch coordinates:");

    gfx->setCursor(10, 295);
    gfx->print("Commands:");

    redrawBtnStatus();
    drawScreenBtns();
    redrawLog();
}

void redrawBtnStatus() {
    for (int i = 0; i < 3; i++) {
        int xo = 10 + i * 105;
        gfx->fillRect(xo, 62, 95, 70, btnBl[i] ? C_GREEN : 0x2104);
        gfx->setTextColor(C_TEXT);
        gfx->setTextSize(2);
        gfx->setCursor(xo + 8, 72);
        char buf[6];
        snprintf(buf, sizeof(buf), "BTN%d", i+1);
        gfx->print(buf);
        gfx->setTextSize(1);
        gfx->setCursor(xo + 8, 100);
        gfx->print(btnBl[i] ? "BL: ON " : "BL: OFF");
        gfx->setCursor(xo + 8, 115);
        gfx->print(btnState[i] ? "PRESSED" : "       ");
    }
}

void drawScreenBtns() {
    for (int i = 0; i < NUM_SCREEN_BTNS; i++) {
        const ScreenBtn &b = screenBtns[i];
        gfx->fillRoundRect(b.x, b.y, b.w, b.h, 6, b.color);
        gfx->setTextColor(0x0000);  // black text
        gfx->setTextSize(1);
        int tw = strlen(b.label) * 6;
        gfx->setCursor(b.x + (b.w - tw)/2, b.y + (b.h - 8)/2);
        gfx->print(b.label);
    }
}

void redrawLog() {
    int y = 150;
    for (int i = 0; i < LOG_LINES; i++) {
        int idx = (logHead + i) % LOG_LINES;
        gfx->fillRect(0, y, TFT_W, 16, C_BG);
        gfx->setTextColor(C_TEXT, C_BG);
        gfx->setTextSize(1);
        gfx->setCursor(10, y + 2);
        if (logLines[idx].length() > 0) {
            String s = logLines[idx];
            if (s.length() > 51) s = s.substring(0, 51);
            gfx->print(s);
        }
        y += 18;
    }
}

// ─── Screen touch handler ─────────────────────────────────────────────────────
void handleScreenTouch(int16_t x, int16_t y) {
    for (int i = 0; i < NUM_SCREEN_BTNS; i++) {
        const ScreenBtn &b = screenBtns[i];
        if (x >= b.x && x < b.x + b.w && y >= b.y && y < b.y + b.h) {
            logAdd(String("Touch: ") + b.label);
            if (i == 0) sendBlinkAll();
            if (i == 1) sendStopAll();
            if (i == 2) sendPingAll();
            if (i == 3) enter433Pairing();
            if (i == 4) sendRS485Ping();
            break;
        }
    }
}

// ─── RS-485 TX ────────────────────────────────────────────────────────────────
void rs485Send(const String &json) {
    digitalWrite(PIN_RS485_MODE, HIGH);
    delayMicroseconds(100);
    RS485.println(json);
    RS485.flush();
    delayMicroseconds(100);
    digitalWrite(PIN_RS485_MODE, LOW);
    Serial.print("[RS485 TX] "); Serial.println(json);
}

// ─── RS-485 RX ────────────────────────────────────────────────────────────────
void handleRS485() {
    static String rxBuf;
    while (RS485.available()) {
        char c = RS485.read();
        if (c == '\n') {
            if (rxBuf.length() > 0) {
                Serial.print("[RS485 RX] "); Serial.println(rxBuf);

                StaticJsonDocument<256> doc;
                DeserializationError err = deserializeJson(doc, rxBuf);
                if (!err) {
                    const char *type = doc["type"] | "";

                    if (strcmp(type, "rs485_pong") == 0) {
                        String mac = doc["mac"] | "?";
                        logAdd("SV alive: " + mac);
                    } else if (strcmp(type, "ping_reply") == 0) {
                        String mac  = doc["mac"] | "??:??:??:??:??:??";
                        float  batt = doc["battery"] | 0.0f;
                        logAdd("Pong " + mac.substring(9) + " " + String(batt,1)+"V");
                    } else if (strcmp(type, "433rx") == 0) {
                        unsigned long code = doc["code"] | 0UL;
                        int bits = doc["bits"] | 0;
                        logAdd("SV 433: " + String(code) + " b=" + String(bits));
                    } else if (strcmp(type, "espnow_rx") == 0) {
                        const char *mac = doc["mac"] | "?";
                        const char *cmd = doc["cmd"] | "?";
                        logAdd(String("RX ") + String(mac).substring(9) + " " + cmd);
                    } else {
                        logAdd(String("RS485: ") + rxBuf.substring(0, 40));
                    }
                } else {
                    logAdd("RS485 parse err");
                }
                rxBuf = "";
            }
        } else {
            if (rxBuf.length() < 255) rxBuf += c;
        }
    }
}

// ─── Command senders ──────────────────────────────────────────────────────────
void sendBlinkAll() {
    String json = "{\"type\":\"cmd\",\"mac\":\"broadcast\","
                  "\"action\":\"blink\",\"duration\":5000,\"buzzer\":true}";
    rs485Send(json);
    logAdd(">> Blink All sent");
    for (int i = 0; i < 3; i++) {
        btnBl[i] = true;
        digitalWrite(BTN_BL[i], HIGH);
    }
    redrawBtnStatus();
}

void sendStopAll() {
    String json = "{\"type\":\"cmd\",\"mac\":\"broadcast\",\"action\":\"stop\"}";
    rs485Send(json);
    logAdd(">> Stop All sent");
    for (int i = 0; i < 3; i++) {
        btnBl[i] = false;
        digitalWrite(BTN_BL[i], LOW);
    }
    redrawBtnStatus();
}

void sendPingAll() {
    String json = "{\"type\":\"ping\",\"mac\":\"broadcast\"}";
    rs485Send(json);
    logAdd(">> Ping All");
}

void sendRS485Ping() {
    rs485Send("{\"type\":\"rs485_ping\"}");
    logAdd(">> RS485 Ping");
}

void enter433Pairing() {
    pairingMode433 = true;
    logAdd("433 Pair: waiting for remote...");
    for (int i = 0; i < 3; i++) {
        digitalWrite(BTN_BL[i], HIGH);
    }
    delay(200);
    for (int i = 0; i < 3; i++) {
        digitalWrite(BTN_BL[i], LOW);
    }
}

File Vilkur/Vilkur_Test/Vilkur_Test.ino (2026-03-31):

/*
 * Vilkur_Test.ino — Hardware test sketch for Vilkur PCB (ESP32-C3 Supermini)
 *
 * Tests:
 *   - LED group 1 (GPIO 4), LED group 2 (GPIO 3), piezo buzzer (GPIO 2)
 *   - Pairing feedback LED (GPIO 1)
 *   - Battery voltage ADC (GPIO 5, ×4 divider)
 *   - Rotary channel switch (GPIO 10/20/21, active-LOW, 3-position)
 *   - External signal input (GPIO 8)
 *   - Pairing button (GPIO 9, active-LOW, hold 3 s for pairing mode)
 *   - 433 MHz reception (RXB6 on GPIO 0, RCSwitch library)
 *   - ESP-NOW receive/transmit (broadcast)
 *
 * Serial monitor: 115200 baud
 * Board: ESP32C3 Dev Module
 * Required libraries: RCSwitch (by sui77)
 *
 * RS-485 JSON protocol (shared across all boards):
 *   CMD_BLINK       0x01  — blink LEDs (+optional buzzer) for duration ms
 *   CMD_STOP        0x02  — stop blinking
 *   CMD_DISABLE_433 0x03  — stop listening to 433 MHz
 *   CMD_PING        0x04  — ping: Vilkur replies with CMD_PONG + battery voltage
 *   CMD_PONG        0x05  — ping reply
 */

#include <WiFi.h>
#include <esp_now.h>
#include <esp_wifi.h>
#include <RCSwitch.h>

// ─── Pin definitions ─────────────────────────────────────────────────────────
#define PIN_433_DATA    0   // RXB6 data output (strapping pin – idle HIGH)
#define PIN_LED_PAIR    1   // Pairing feedback LED
#define PIN_BUZZER      2   // Piezo buzzer via MOSFET
#define PIN_LED2        3   // LED group 2 via MOSFET
#define PIN_LED1        4   // LED group 1 via MOSFET
#define PIN_BATT_ADC    5   // Battery ADC (reads ¼ of real voltage)
#define PIN_EXT_SIG     8   // External signal (HIGH when bridged)
#define PIN_PAIR_BTN    9   // Pairing button (active LOW)
#define PIN_ROT_CH1    10   // Rotary switch pos 1 → channel 1  (LOW = selected)
#define PIN_ROT_CH2    20   // Rotary switch pos 2 → channel 6
#define PIN_ROT_CH3    21   // Rotary switch pos 3 → channel 11

// ─── ESP-NOW message struct (must match SaatjaVastuvõtja) ────────────────────
#define CMD_BLINK       0x01
#define CMD_STOP        0x02
#define CMD_DISABLE_433 0x03
#define CMD_PING        0x04
#define CMD_PONG        0x05

struct EspNowMsg {
    uint8_t  cmd;
    uint16_t duration;   // ms (used with CMD_BLINK)
    bool     buzzer;     // enable buzzer with blink
    float    battery;    // battery voltage (sent in CMD_PONG)
};

// ─── Globals ─────────────────────────────────────────────────────────────────
RCSwitch rf433;

bool     blink433Active  = false;   // currently listening to 433 MHz?
uint32_t lastEspNowMs    = 0;       // last ESP-NOW message timestamp
bool     blinkActive     = false;   // currently executing a blink command
uint32_t blinkEndMs      = 0;
bool     blinkBuzzer     = false;
uint32_t blinkToggleMs   = 0;
bool     blinkState      = false;

bool     pairingMode     = false;
uint32_t pairBtnDownMs   = 0;
uint32_t pairedCode      = 0;       // stored 433 MHz code (0 = not paired)

uint8_t  broadcastAddr[6] = {0xFF,0xFF,0xFF,0xFF,0xFF,0xFF};

// ─── Forward declarations ─────────────────────────────────────────────────────
void menuPrint();
int  readRotaryChannel();
float readBatteryVoltage();
void selfTest();
void startBlink(uint16_t durationMs, bool buzz);
void stopBlink();
void updateBlink();
void sendPong();
void enable433(bool enable);
void onEspNowRecv(const esp_now_recv_info_t *recv_info, const uint8_t *data, int len);
void onEspNowSend(const wifi_tx_info_t *tx_info, esp_now_send_status_t status);

// ─── Setup ───────────────────────────────────────────────────────────────────
void setup() {
    Serial.begin(115200);
    delay(500);
    Serial.println("\n=== Vilkur Test Sketch ===");

    // Output pins
    pinMode(PIN_LED_PAIR, OUTPUT);
    pinMode(PIN_BUZZER,   OUTPUT);
    pinMode(PIN_LED2,     OUTPUT);
    pinMode(PIN_LED1,     OUTPUT);
    digitalWrite(PIN_LED_PAIR, LOW);
    digitalWrite(PIN_BUZZER,   LOW);
    digitalWrite(PIN_LED2,     LOW);
    digitalWrite(PIN_LED1,     LOW);

    // Input pins
    pinMode(PIN_EXT_SIG,  INPUT);
    pinMode(PIN_PAIR_BTN, INPUT_PULLUP);
    pinMode(PIN_ROT_CH1,  INPUT_PULLUP);
    pinMode(PIN_ROT_CH2,  INPUT_PULLUP);
    pinMode(PIN_ROT_CH3,  INPUT_PULLUP);

    // ADC
    analogReadResolution(12);
    analogSetAttenuation(ADC_11db); // full-scale ~3.3 V

    // 433 MHz – RCSwitch
    rf433.enableReceive(PIN_433_DATA);
    blink433Active = true;
    Serial.println("433 MHz: listening");

    // ESP-NOW
    int channel = readRotaryChannel();
    Serial.printf("Rotary switch: channel %d\n", channel);

    WiFi.mode(WIFI_STA);
    WiFi.disconnect();
    esp_wifi_set_channel(channel, WIFI_SECOND_CHAN_NONE);

    if (esp_now_init() != ESP_OK) {
        Serial.println("ERROR: esp_now_init() failed");
    } else {
        esp_now_register_recv_cb(onEspNowRecv);
        esp_now_register_send_cb(onEspNowSend);

        // Register broadcast peer
        esp_now_peer_info_t peer = {};
        memcpy(peer.peer_addr, broadcastAddr, 6);
        peer.channel = channel;
        peer.encrypt = false;
        esp_now_add_peer(&peer);

        Serial.printf("ESP-NOW ready on channel %d\n", channel);
        Serial.print("My MAC: ");
        Serial.println(WiFi.macAddress());
    }

    selfTest();
    menuPrint();
    lastEspNowMs = millis();
}
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

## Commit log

2026-02-28 Added schematic
2026-02-28 Fix previous commitS
    [Baka.PrjPcb, PcbLib1.PcbLib, Schlib1.SchLib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]
2026-03-03 Pcb arendus ja mõõtmiste visualiseering
    [Baka.PrjPcb, Schlib1.SchLib, Sheet2.SchDoc]
2026-03-03 PCB arendus ja visauliseering mõõtmistest
2026-03-13 Added V1 final PCB design
    [Baka.PrjPcb, KontrollKast.PrjPcb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]
2026-03-31 New pcb designs
    [KontrollKast.PrjPcb, PCB2.PcbDoc, Sheet1.SchDoc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]
